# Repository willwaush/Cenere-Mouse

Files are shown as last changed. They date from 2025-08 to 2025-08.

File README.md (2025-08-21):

# 🖱️ Cenere Mouse (Open Source Tri-Mode Connectivity)

<p align="center">
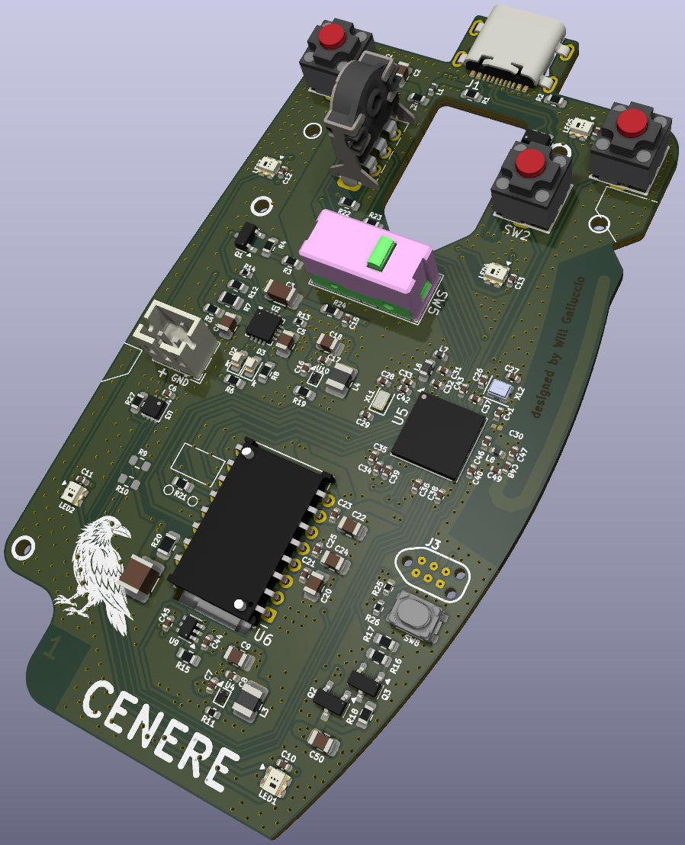
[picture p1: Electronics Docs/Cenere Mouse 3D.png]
3D Render of PCB
  
</p>

---

## 🔎 Project Overview

This project is an **open-source tri-mode connectivity gaming mouse**, designed around the **Nordic nRF52840** SoC.  
It supports three connectivity modes:

- **USB HID**  
- **Bluetooth Low Energy (BLE)**  
- **Nordic 2.4 GHz Wireless protocol**  

### ✨ Key Features
- Custom **monopole 2.4 GHz PCB antenna** optimized for the nRF52840  
- **PixArt PAW3395 optical sensor** for high-precision tracking  
- **Battery charging circuit** to support Bluetooth and Wireless power  
- **DC/DC Supply** to achieve maximum efficiency, low energy consumption
- **Addressable RGB LEDs** to optionally enable some aestethic glowing effect
- Fully open-source hardware and firmware*

---

## 📐 PCB Layer Previews

The design is a **4-layer PCB**, manufactured by **JLCPCB**, chosen for their reliable stackup and cost-effective prototyping services.  

<p align="center">
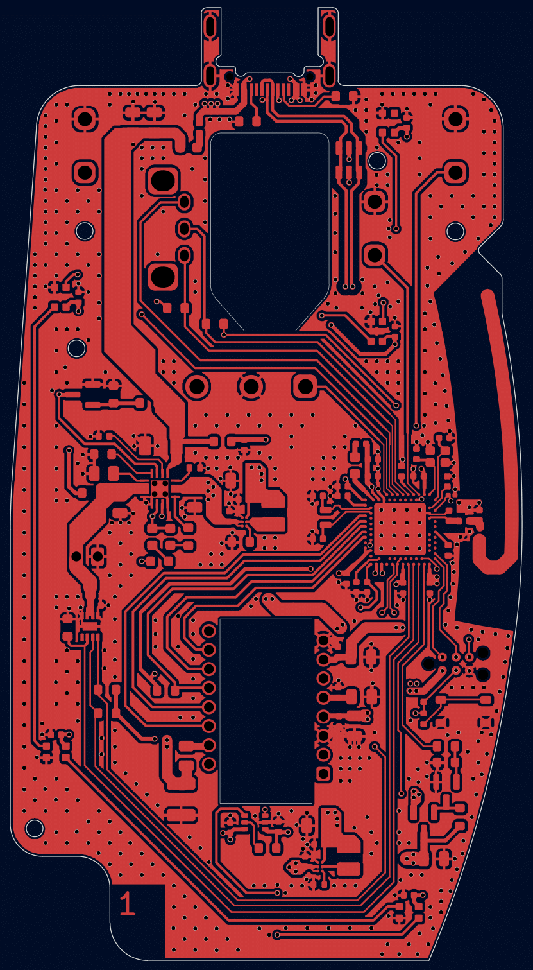
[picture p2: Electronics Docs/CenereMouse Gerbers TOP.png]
PCB Layer 1 - TOP
  
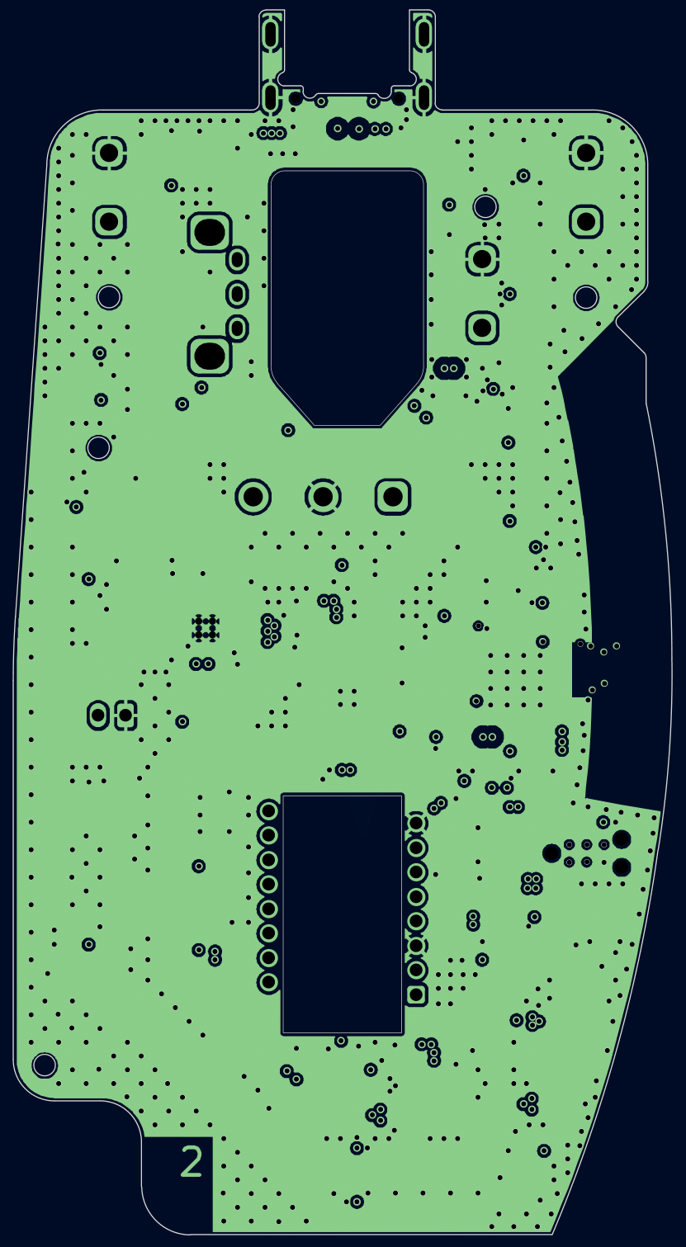
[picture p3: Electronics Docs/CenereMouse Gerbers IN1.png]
PCB Layer 2 - IN1
  
</p>

<p align="center">
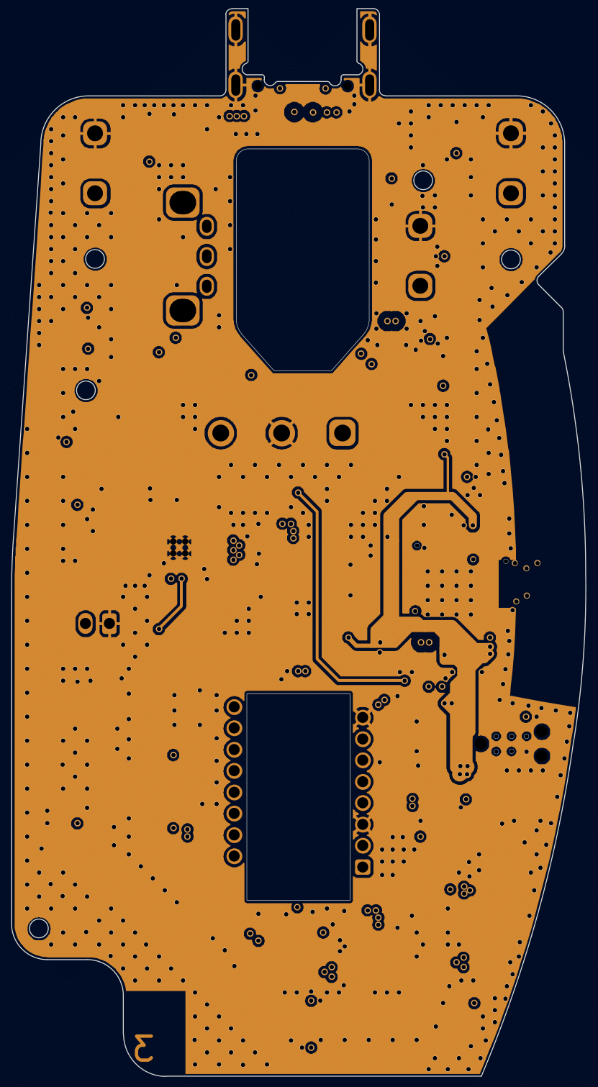
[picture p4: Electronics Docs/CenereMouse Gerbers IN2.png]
PCB Layer 3 - IN2
  
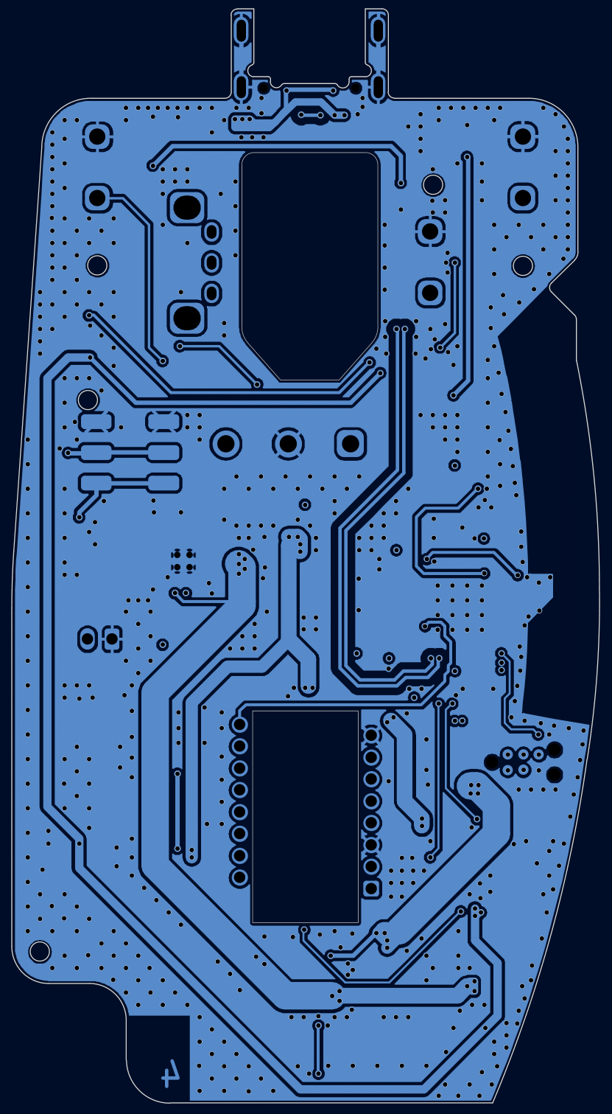
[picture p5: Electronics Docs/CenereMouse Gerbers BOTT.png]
PCB Layer 4 - BOTTOM
  
</p>

<p align="center">
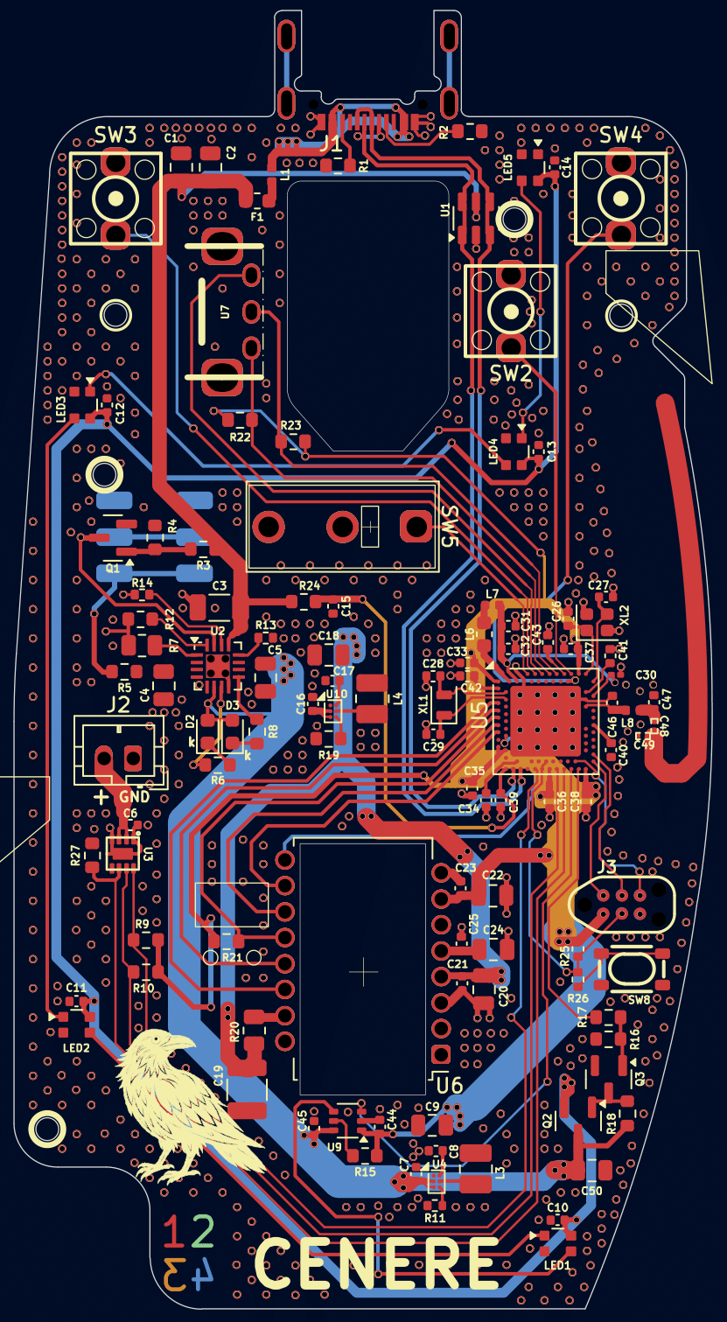
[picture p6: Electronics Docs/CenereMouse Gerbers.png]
All PCB Layers Together
  
</p>

---

## 🏗️ PCB Stackup (JLCPCB)

The board will be fabricated at **JLCPCB** with the following stackup:

- **Top Layer (Copper, 35 µm)** – signal + components  
- **Prepreg (0.2104 mm, Dk ≈ 4.4)** – dielectric (7628*1) 
- **Mid Layer 1 (Copper, 152 µm)** – ground/pwr
- **Core (1.065 mm, Dk ≈ 4.6)** – dielectric (FR4)
- **Mid Layer 2 (Copper, 152 µm)** – ground/pwr
- **Prepreg (0.2104 mm, Dk ≈ 4.4)** – dielectric (7628*1) 
- **Bottom Layer (Copper, 35 µm)** – signal + components

This configuration provides an easy to work with controlled impedance environment for the **high speed signals** as well as the **RF Section**.

---

## 🚀 Goals

- Provide a **fully open-source reference design** for hobbyists, makers, and researchers  
- Explore advanced **antenna design** on low-cost PCB fabrication  
- Enable experimentation with **custom gaming peripherals**  

---

## 📂 Repository Structure

/Kicad Files        → KiCad design files
/Electronics Docs   → Documentation, layer renders, diagrams

Work in progress..

---

## 📜 License

This project uses a **dual-license** model:

- **Software (Code)** → [GNU GPL v3.0](LICENSES/GPL-3.0.txt) with a **Non-Commercial Use Exception**  
  - You may use, modify, and redistribute the source code for **personal, educational, or research** purposes.  
  - **Commercial use is prohibited** without prior written permission.  
  - Attribution is required.

- **Hardware (Schematics, PCB Layouts, Documentation)** → [CC BY-NC 4.0](LICENSES/CC-BY-NC-4.0.txt)  
  - You may copy, redistribute, remix, and adapt the hardware files.  
  - **Commercial use is prohibited.**  
  - Attribution is required.

### Attribution Requirement

If you use this project (code or hardware) in your own work, you must credit:

**© [Your Name or Handle] – [Year]**  
Repo: [GitHub Repository URL]

Example attribution:  
> “Based on the open-source design/code by [Your Name], available at [GitHub Repo URL].”

### Commercial Use

For commercial licensing, please contact the author.

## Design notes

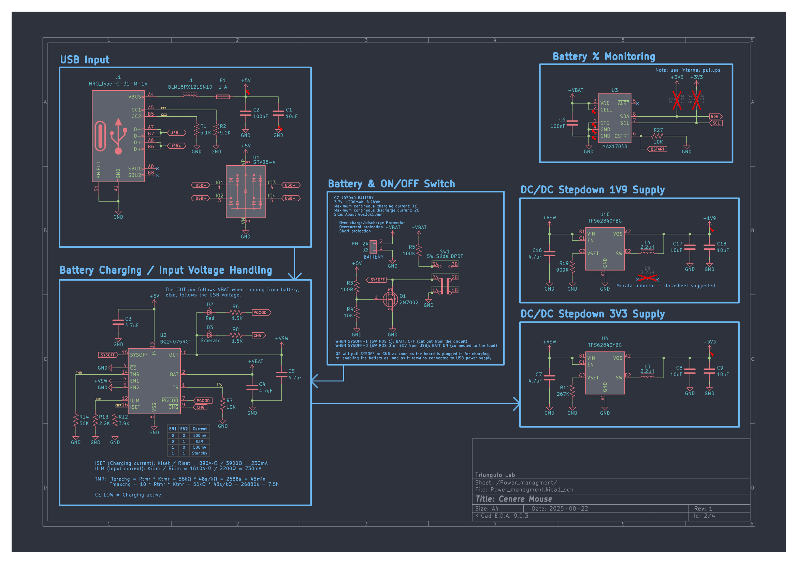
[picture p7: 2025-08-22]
Electronics Docs/Schematic-PowerManagment.png

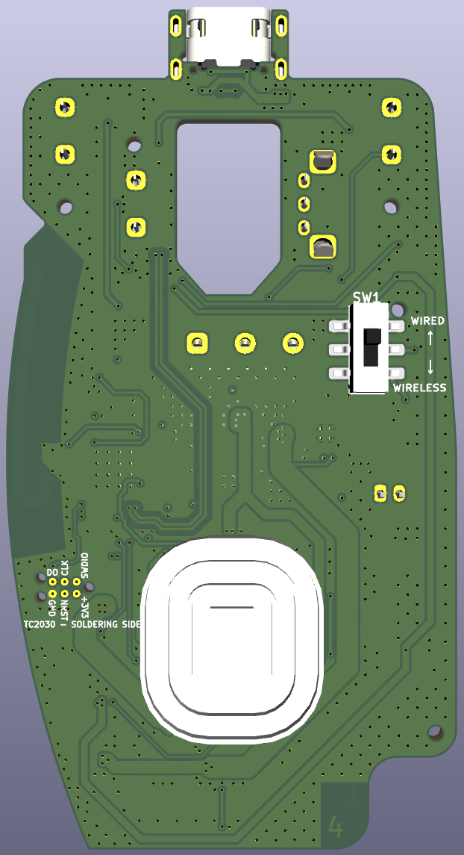
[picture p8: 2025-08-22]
Electronics Docs/Cenere Mouse Back 3D.png

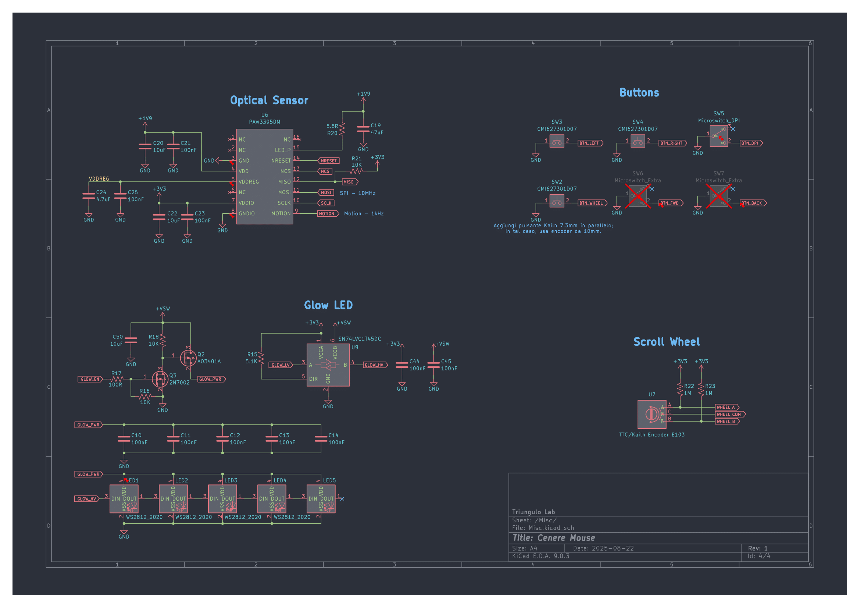
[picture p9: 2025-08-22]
Electronics Docs/Schematic-Misc.png

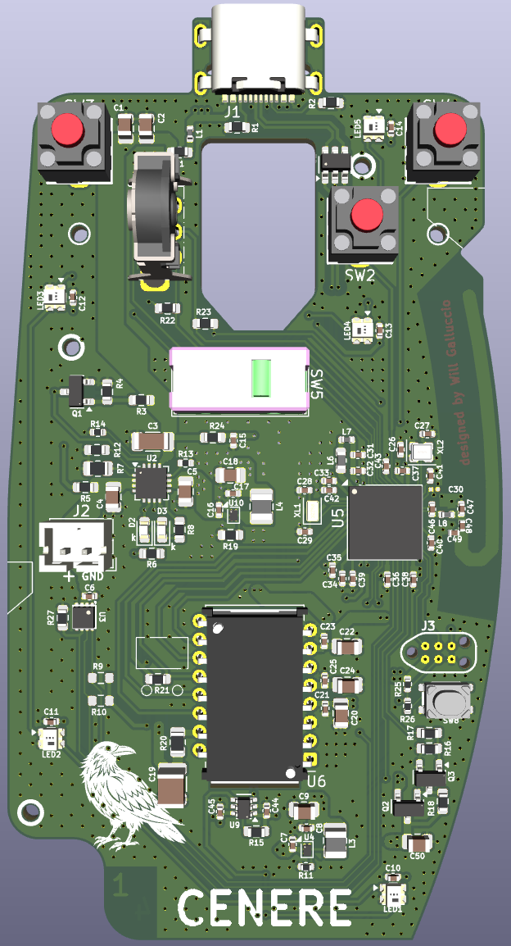
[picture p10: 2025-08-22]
Electronics Docs/Cenere Mouse Front 3D.png

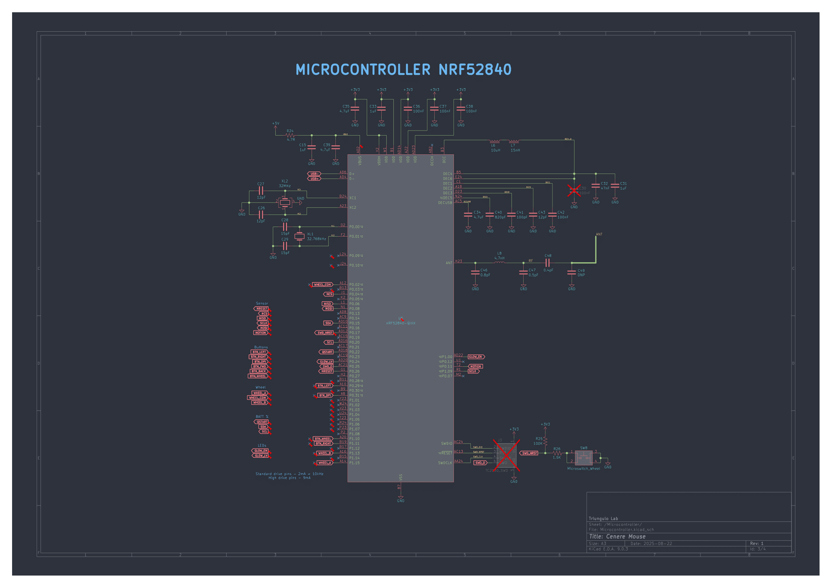
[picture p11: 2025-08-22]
Electronics Docs/Schematic-Microcontroller.png

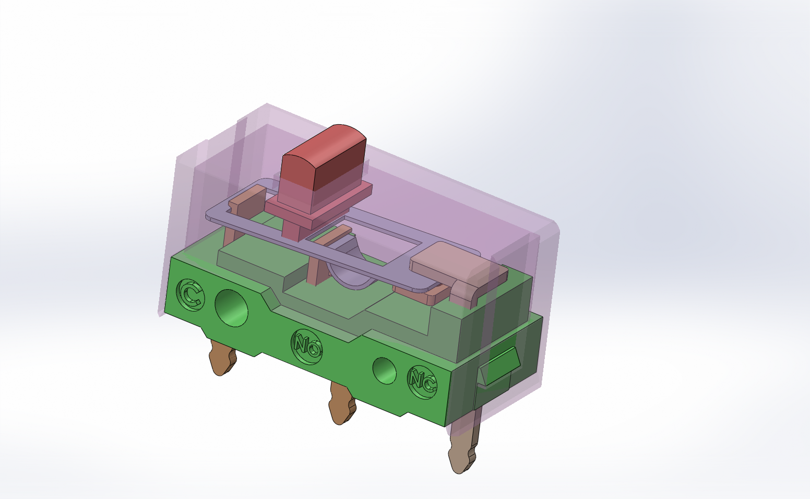
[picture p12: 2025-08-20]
Kicad Files/Extra Libs/tiny-switch-kailh-mouse-1.snapshot.2/SWITCH_MOUSE.PNG

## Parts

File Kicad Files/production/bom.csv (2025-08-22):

Designator | Footprint | Quantity | Value | LCSC Part #
C1, C18, C20, C22, C50, C9 | 0805 | 6 | 10uF | C95841
C10, C11, C12, C13, C14, C21, C23, C25, C36, C37, C38, C42, C44, C45, C6 | 0402 | 15 | 100nF | C307331
C15, C31, C33 | 0402 | 3 | 1uF | C52923
C16, C34, C35, C39, C7 | 0402 | 5 | 4.7uF | C23733
C17, C8 | 0402 | 2 | 10uF | C15525
C19 | 1210 | 1 | 47uF | C84494
C2 | 0805 | 1 | 100nF | C49678
C24, C4, C5 | 0805 | 3 | 4.7uF | C6119943
C26, C27, C43 | 0402 | 3 | 12pF | C1547
C28, C29 | 0402 | 2 | 15pF | C1548
C3 | 1206 | 1 | 4.7uF | C29823
C32 | 0402 | 1 | 47nF | C272875
C40 | 0402 | 1 | 820pF | C307452
C41 | 0402 | 1 | 100pF | C1546
C46 | 0402 | 1 | 0.8pF | C88902
C47 | 0402 | 1 | 0.5pF | C2912277
C48 | Z0201 RF Antenna Path | 1 | 0.4pF | C710805
D2 | 0603 | 1 | Red | C2286
D3 | 0603 | 1 | Emerald | C5121471
F1 | 0603 | 1 | 1 A | C151139
J1 | USB_C_Receptacle_HRO_TYPE-C-31-M-14 | 1 | HRO_Type-C-31-M-14 | C223907
J2 | JST_PH_B2B-PH-K_1x02_P2.00mm_Vertical | 1 | PH-2A | C2319
L1 | 0402 | 1 | BLM15PX121SN1D | C88970
L3, L4 | 1008 | 2 | 2.2uH | C5832372
L6 | 0603 | 1 | 10uH | C86752
L7 | 0402 | 1 | 15nH | C668460
L8 | 0402 | 1 | 4.7nH | C86065
LED1, LED2, LED3, LED4, LED5 | LED_WS2812_2020 | 5 | WS2812_2020 | C965555
Q1, Q3 | SOT-23 | 2 | 2N7002 | C8545
Q2 | SOT-23 | 1 | AO3401A | C347476
R1, R15, R2 | 0603 | 3 | 5.1K | C23186
R11 | 0402 | 1 | 267K | C2998050
R12 | 0603 | 1 | 3.9K | C23018
R13 | 0402 | 1 | 2.2K | C25879
R14 | 0402 | 1 | 56K | C25796
R16, R18, R21, R27, R4 | 0603 | 5 | 10K | C25804
R17, R3 | 0603 | 2 | 100R | C22775
R19 | 0603 | 1 | 909R | C471842
R20 | 0805 | 1 | 5.6R | C17729
R22, R23 | 0603 | 2 | 1M | C22935
R24 | 0603 | 1 | 4.7R | C23164
R25 | 0402 | 1 | 100K | C25741
R26 | 0402 | 1 | 1.5K | C25867
R5 | 0603 | 1 | 100K | C25803
R6, R8 | 0603 | 2 | 1.5K | C22843
R7 | 0805 | 1 | 10K | C17414
SW8 | KEY-SMD_4P-L4.2-W3.2-P2.20-LS4.6 | 1 | Microswitch_Wheel | C139797
U1 | SOT-23-6 | 1 | SRV05-4 | C2836319
U10, U4 | Texas_DSBGA-6_0.76x1.16mm_Layout2x3_P0.4mm | 2 | TPS62840YBG | C2071139
U2 | VQFN-16-1EP_3x3mm_P0.5mm_EP1.6x1.6mm_ThermalVias | 1 | BQ24075RGT | C15464
U3 | TDFN-8-EP_2x2mm_EP_0.8x1.38mm | 1 | MAX17048 | C2682616
U5 | Nordic_AQFN-73-1EP_7x7mm_P0.5mm | 1 | nRF52840-QIXX | C190794
U6 | PixArt_PDIP-16_10.9x16.2mm_P1.78mm | 1 | PAW3395DM
U9 | SOT-363_SC-70-6 | 1 | SN74LVC1T45DC | C9382
XL1 | Crystal_SMD_2012-2Pin_2.0x1.2mm | 1 | 32.768kHz | C7500573
XL2 | Crystal_SMD_2016-4Pin_2.0x1.6mm | 1 | 32MHz | C2965582

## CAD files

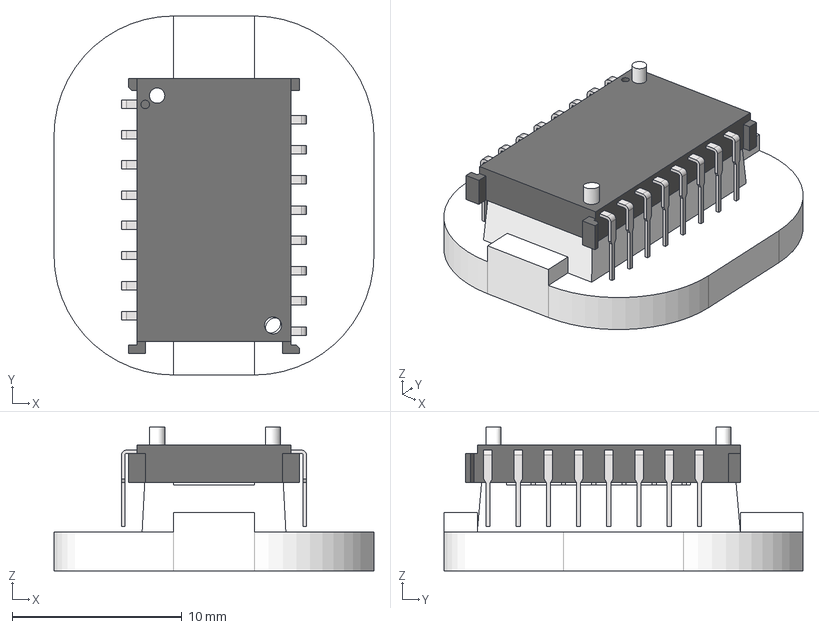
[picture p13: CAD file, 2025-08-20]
Kicad Files/Extra Libs/pmw3360dm-mouse-sensor-1.snapshot.1/PMW3360 v12.step
18.9 x 21.1 x 8.46 mm
Lead x 8
Lead(Mirror) x 8
Lens

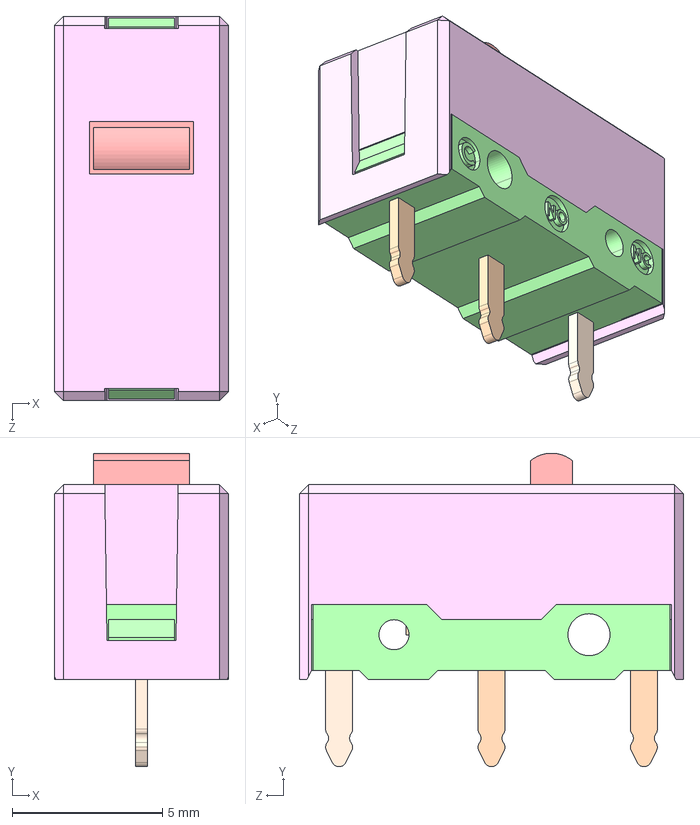
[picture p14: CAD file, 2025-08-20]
Kicad Files/Extra Libs/tiny-switch-kailh-mouse-1.snapshot.2/SWITCH_MOUSE.STEP
5.80 x 10.4 x 12.8 mm

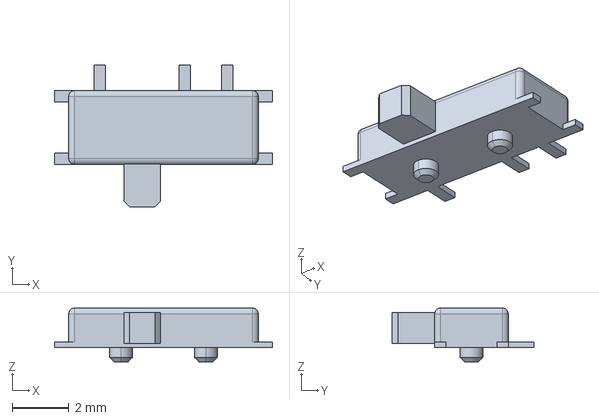
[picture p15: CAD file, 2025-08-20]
Kicad Files/Extra Libs/switch_kps-1290.stp
7.70 x 5.00 x 1.90 mm

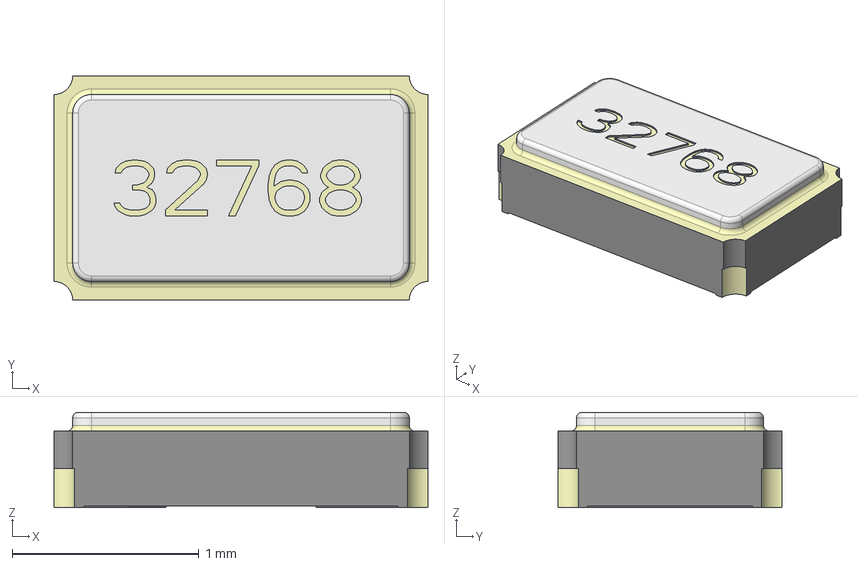
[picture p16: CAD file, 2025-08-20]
Kicad Files/Extra Libs/xsc2012.stp
2.00 x 1.20 x 0.51 mm

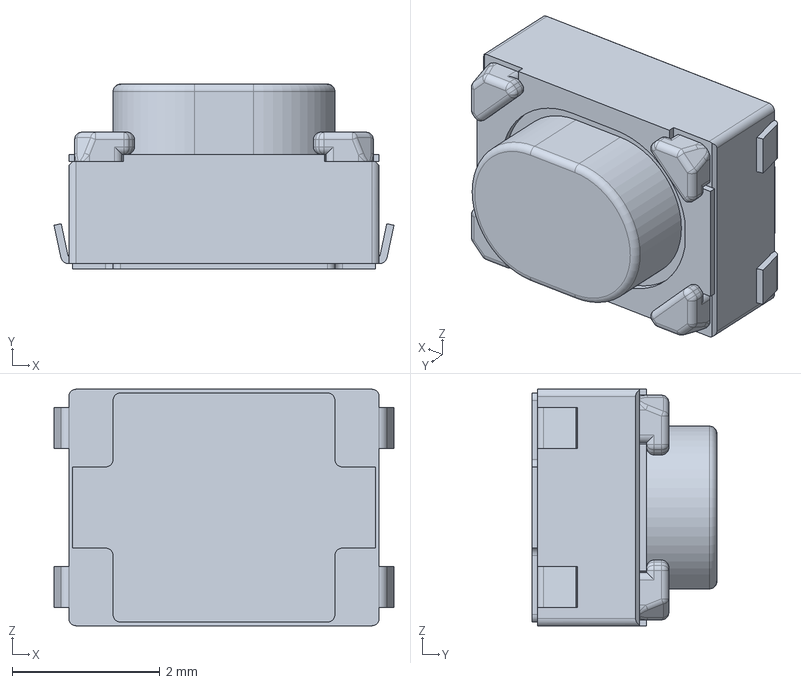
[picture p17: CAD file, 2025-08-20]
Kicad Files/Extra Libs/skrpace010.stp
4.60 x 2.50 x 3.20 mm

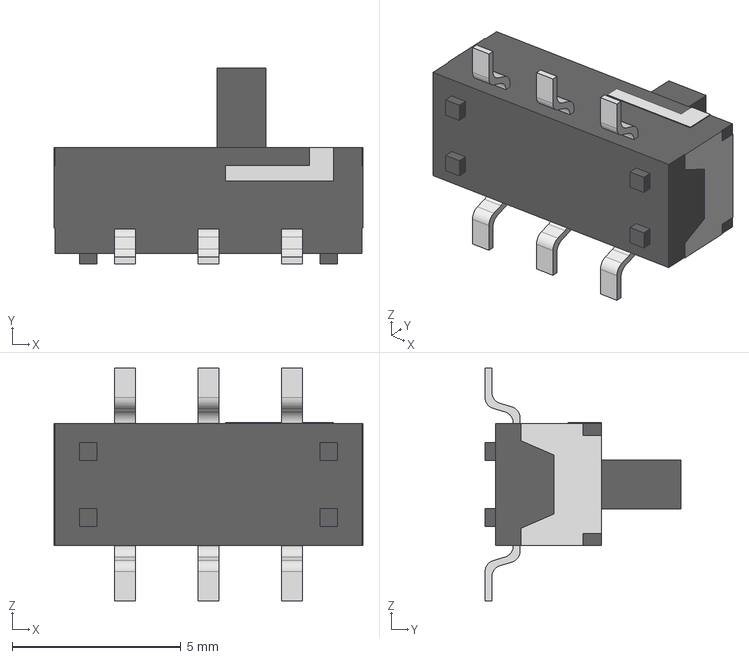
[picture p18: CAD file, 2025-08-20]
Kicad Files/Extra Libs/Selector Switch - MSS22D18.stp
9.17 x 5.82 x 6.91 mm

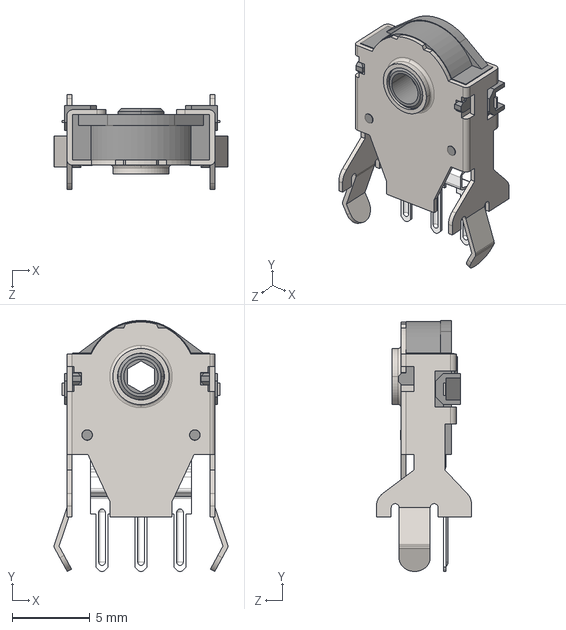
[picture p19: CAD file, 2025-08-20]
Kicad Files/Extra Libs/Alps Encoder 10mm EC10E1220501.stp
11.1 x 16.1 x 6.10 mm

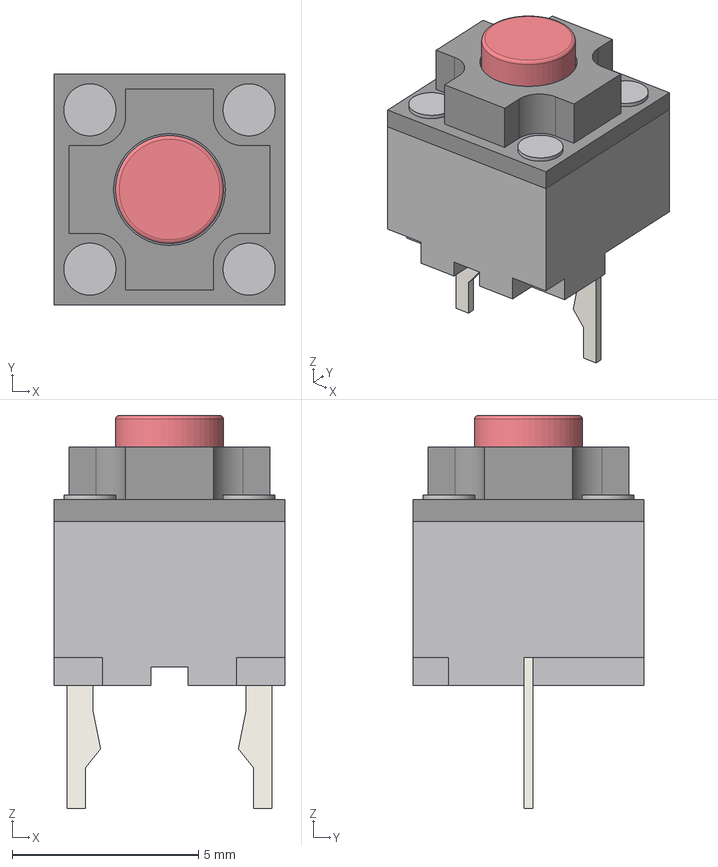
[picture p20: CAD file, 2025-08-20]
Kicad Files/Extra Libs/microSwitch_Kailh_6x6x7.3 (MI627301D07).step
6.20 x 6.20 x 10.6 mm

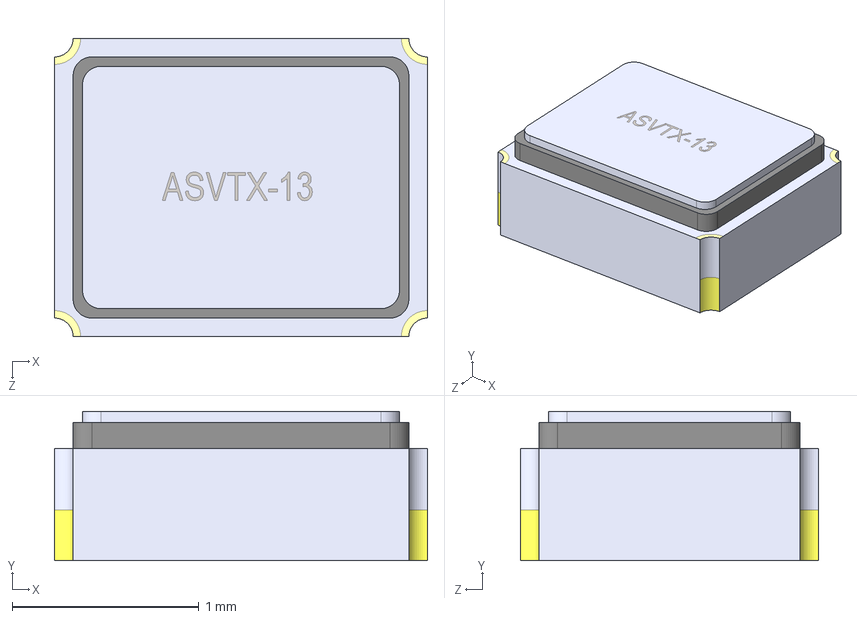
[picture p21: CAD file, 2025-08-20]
Kicad Files/Extra Libs/ASVTX-13.STEP
2.00 x 0.8 x 1.60 mm

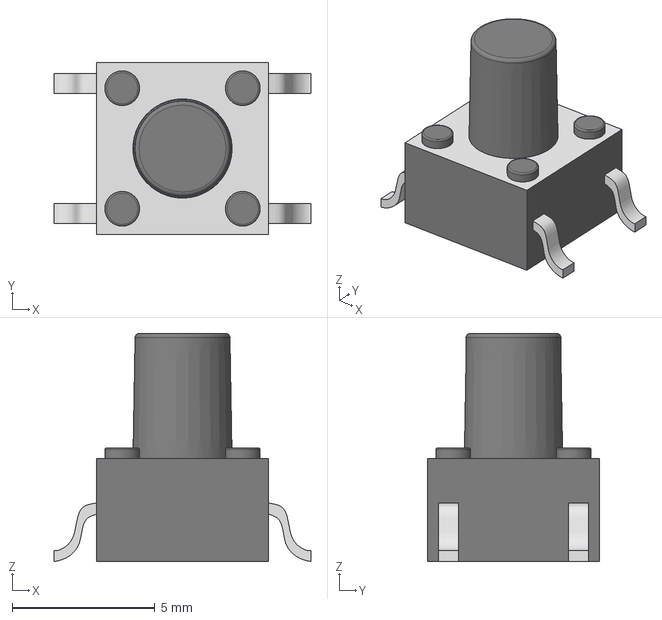
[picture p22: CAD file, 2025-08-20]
Kicad Files/Extra Libs/Tactal Switch - SMD 6x6x8.stp
9.02 x 6.03 x 8.00 mm

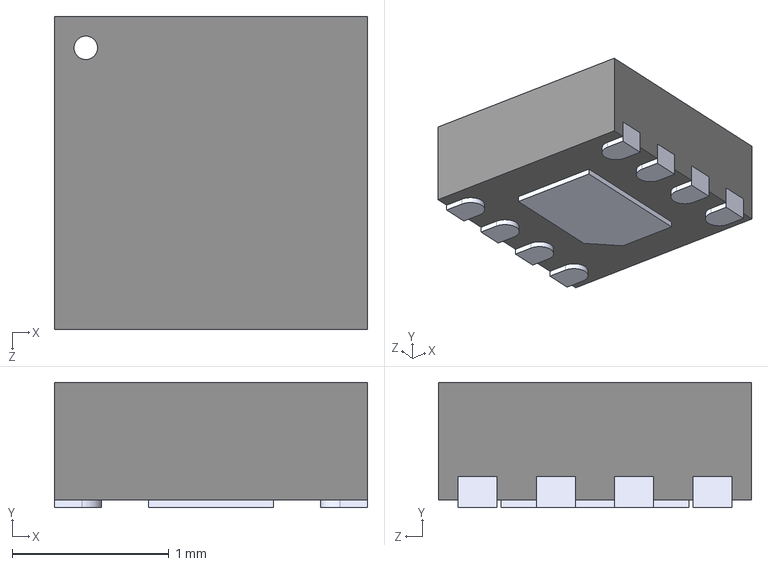
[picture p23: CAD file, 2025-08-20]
Kicad Files/Extra Libs/MAX17048G-T10--3DModel-STEP-510211.STEP
2.00 x 0.8 x 2.00 mm

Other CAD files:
Kicad Files/Extra Libs/pmw3360dm-mouse-sensor-1.snapshot.1/PMW3360 v12.f3d

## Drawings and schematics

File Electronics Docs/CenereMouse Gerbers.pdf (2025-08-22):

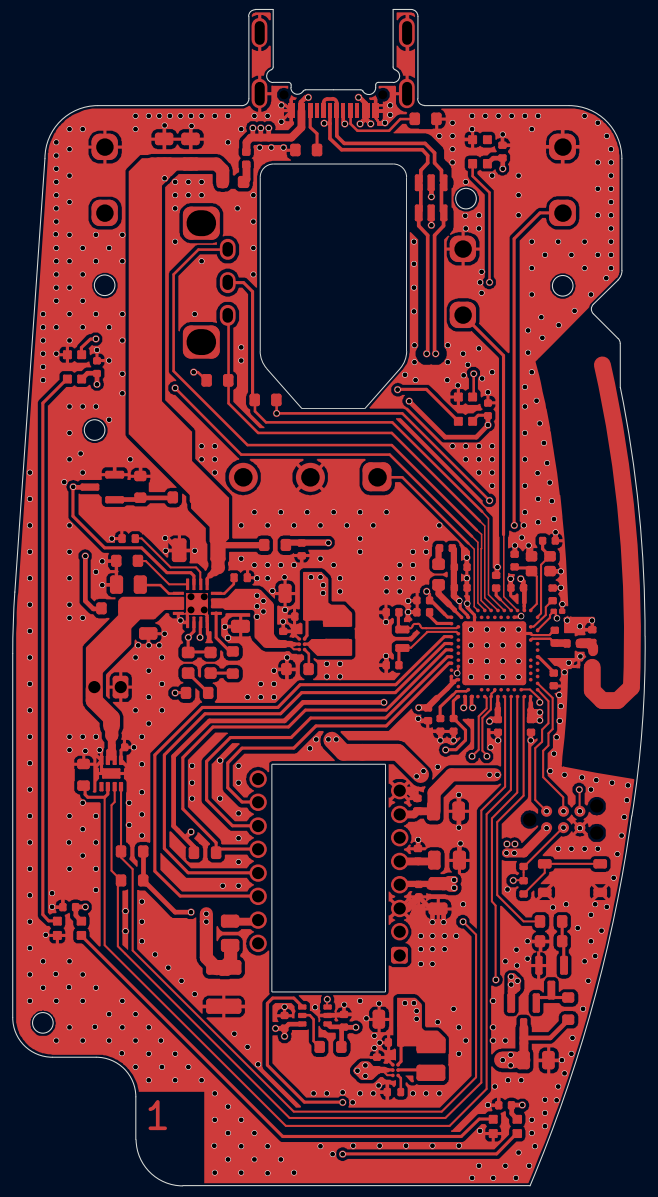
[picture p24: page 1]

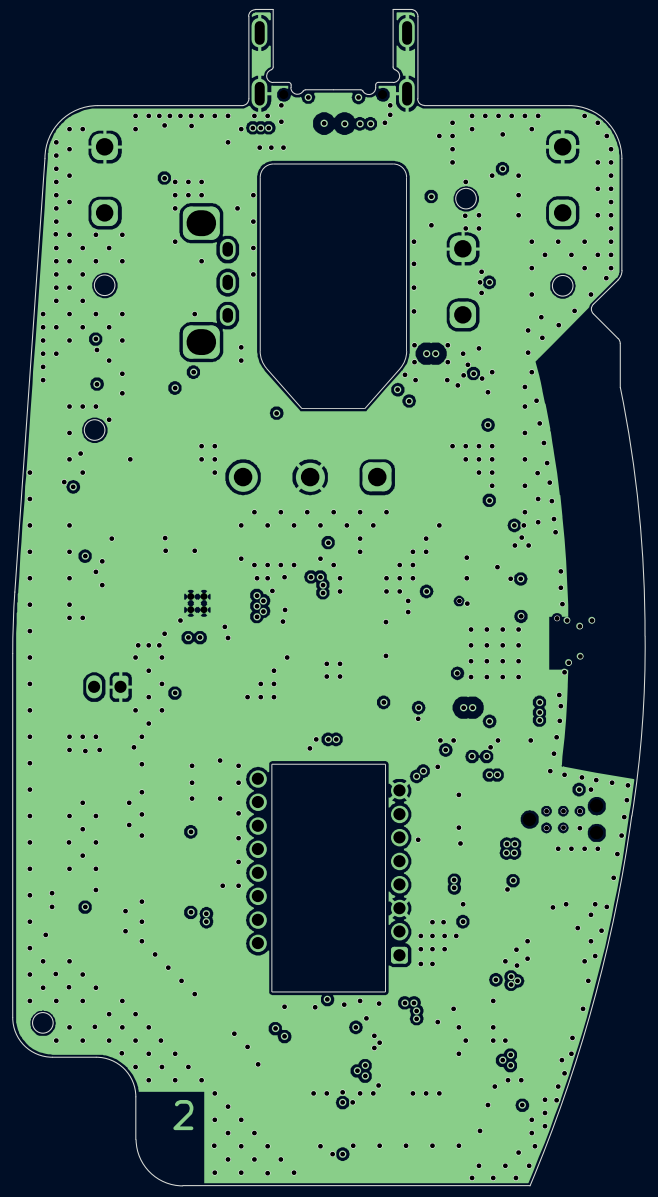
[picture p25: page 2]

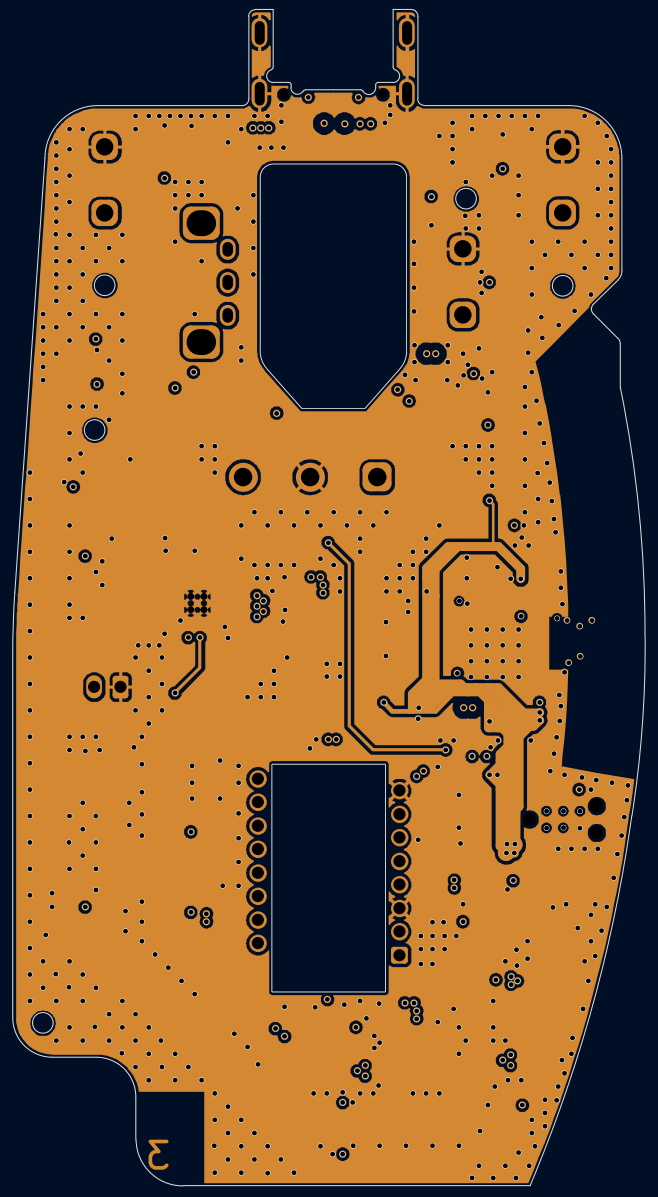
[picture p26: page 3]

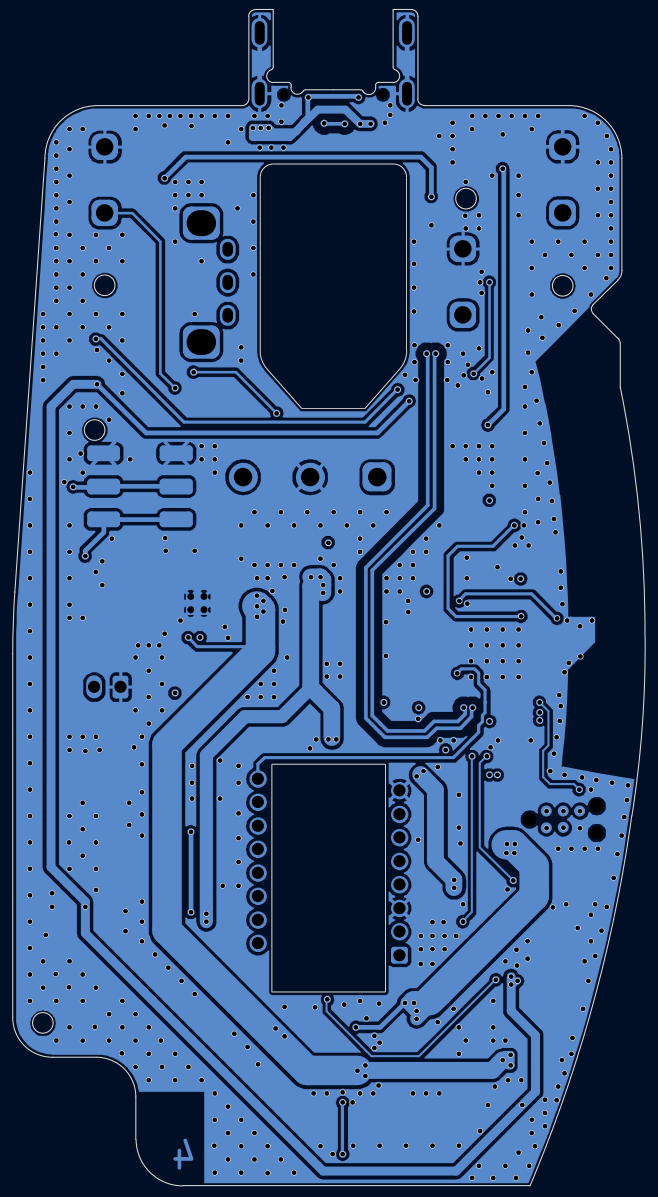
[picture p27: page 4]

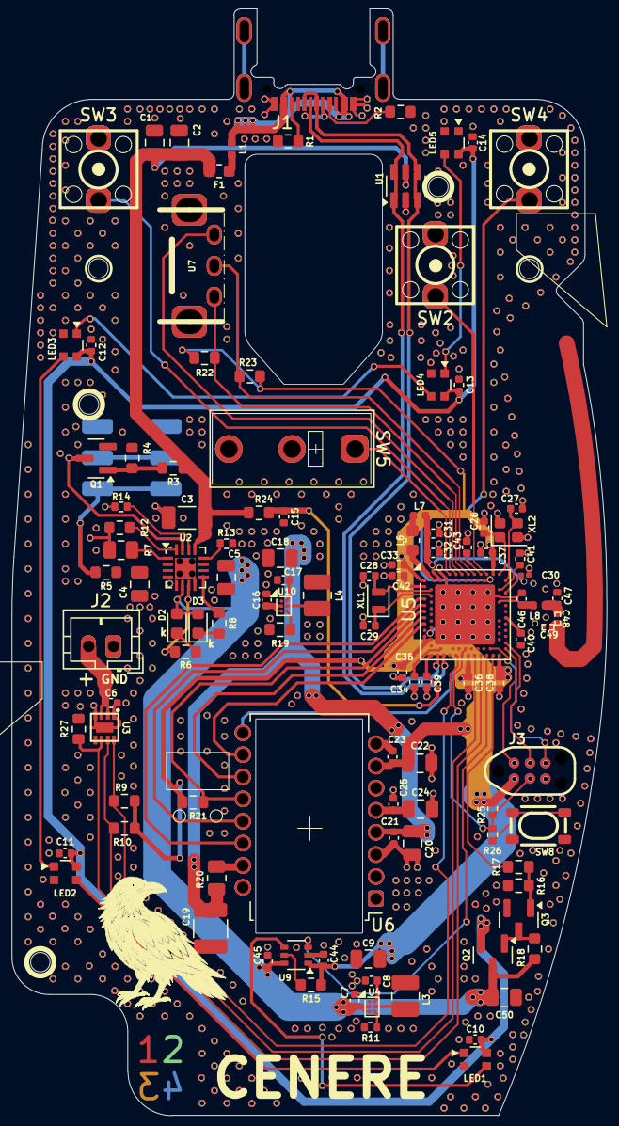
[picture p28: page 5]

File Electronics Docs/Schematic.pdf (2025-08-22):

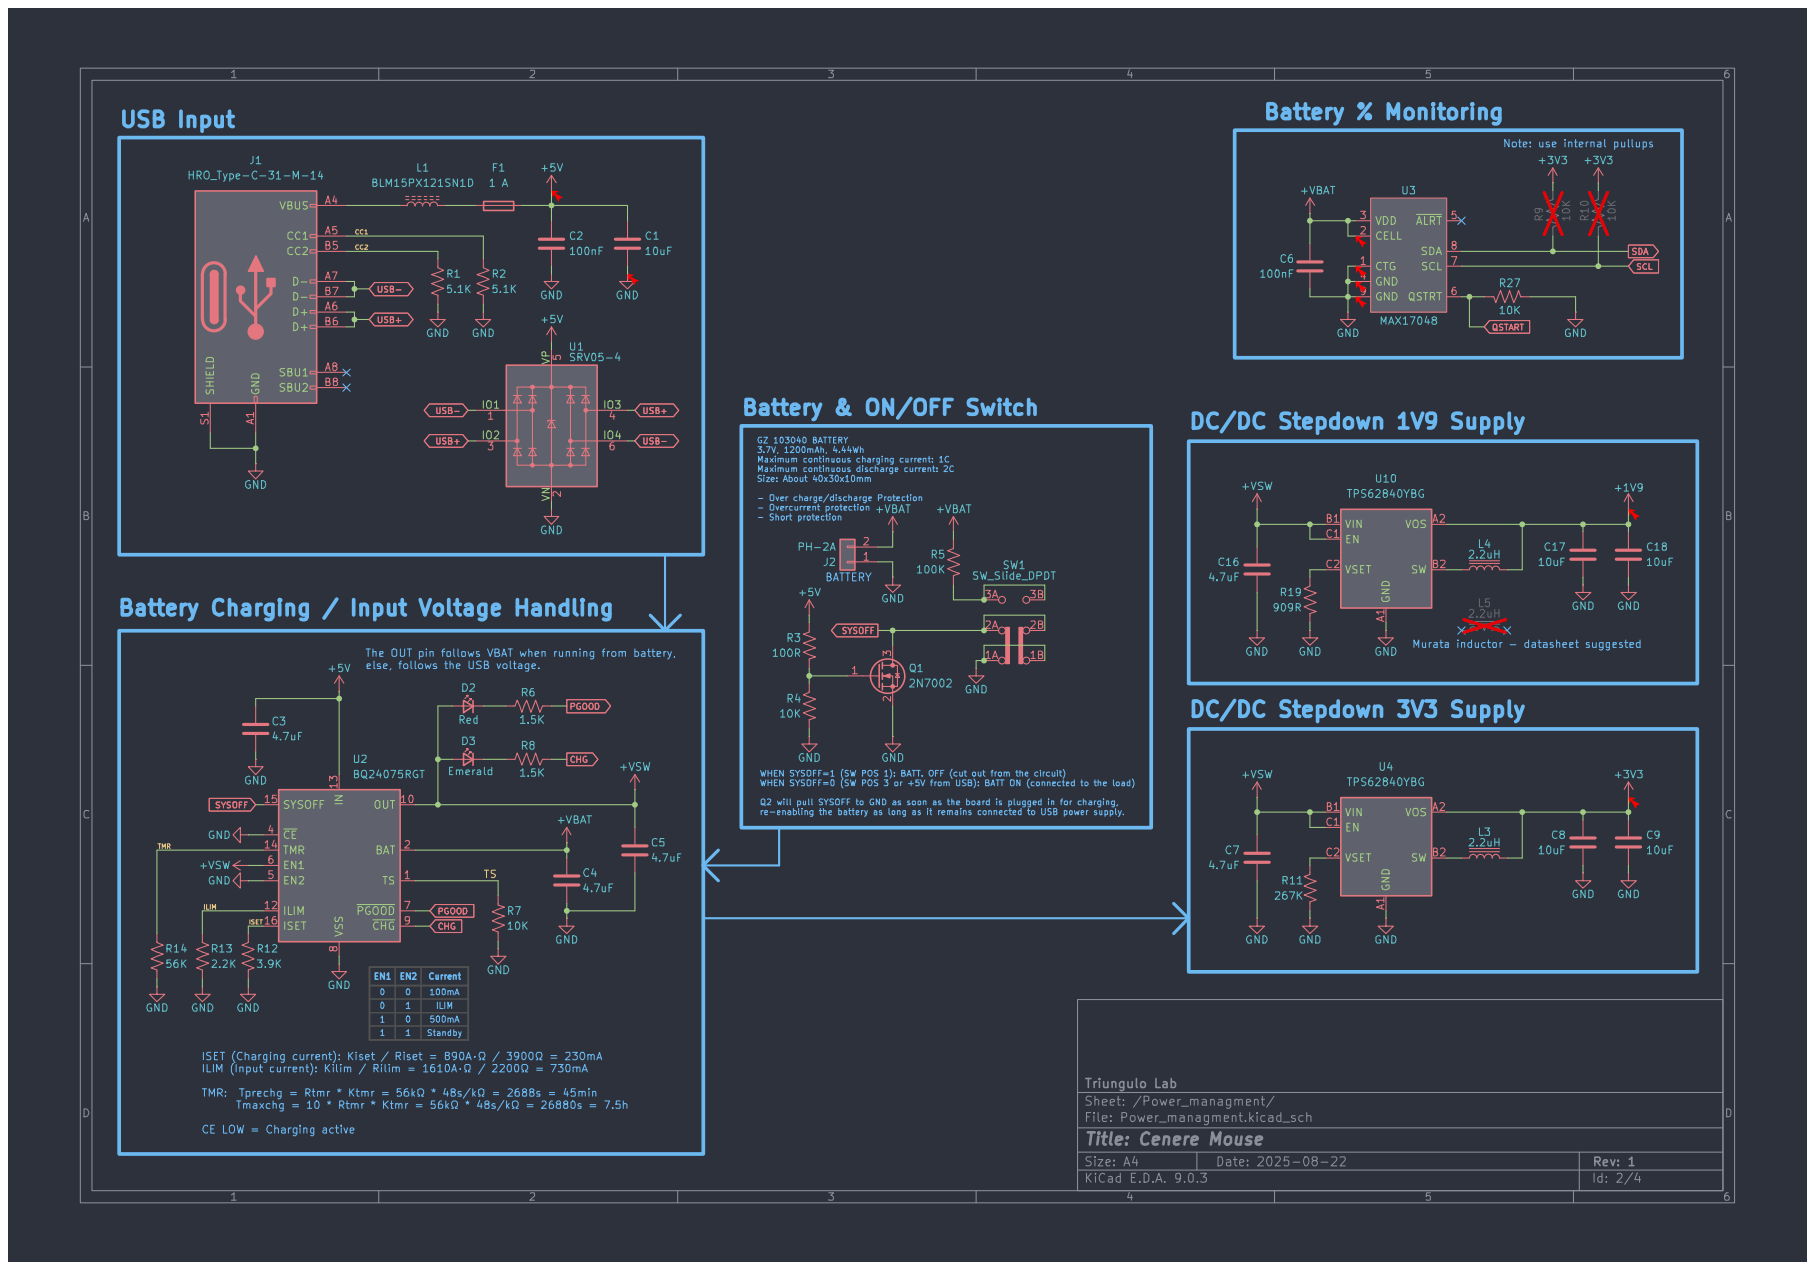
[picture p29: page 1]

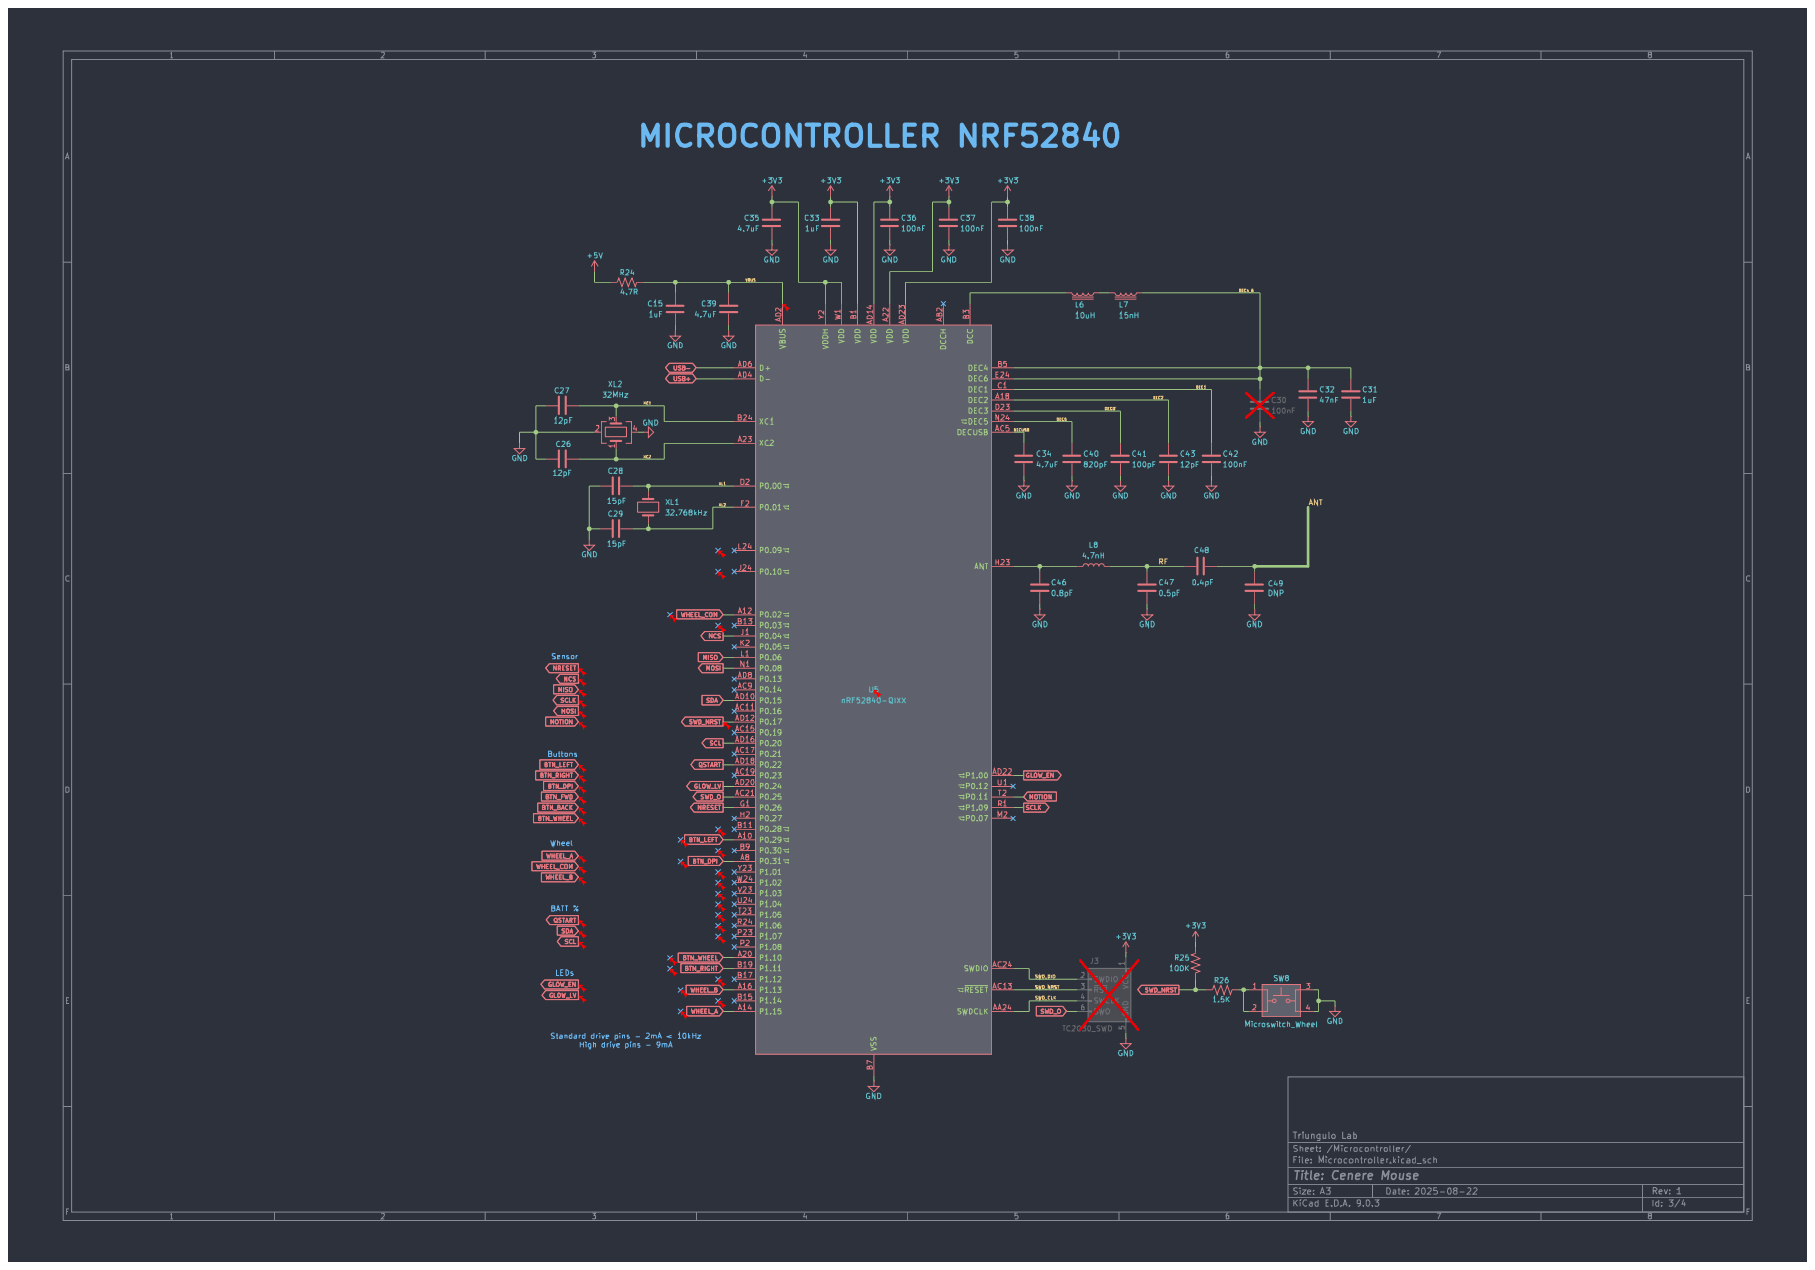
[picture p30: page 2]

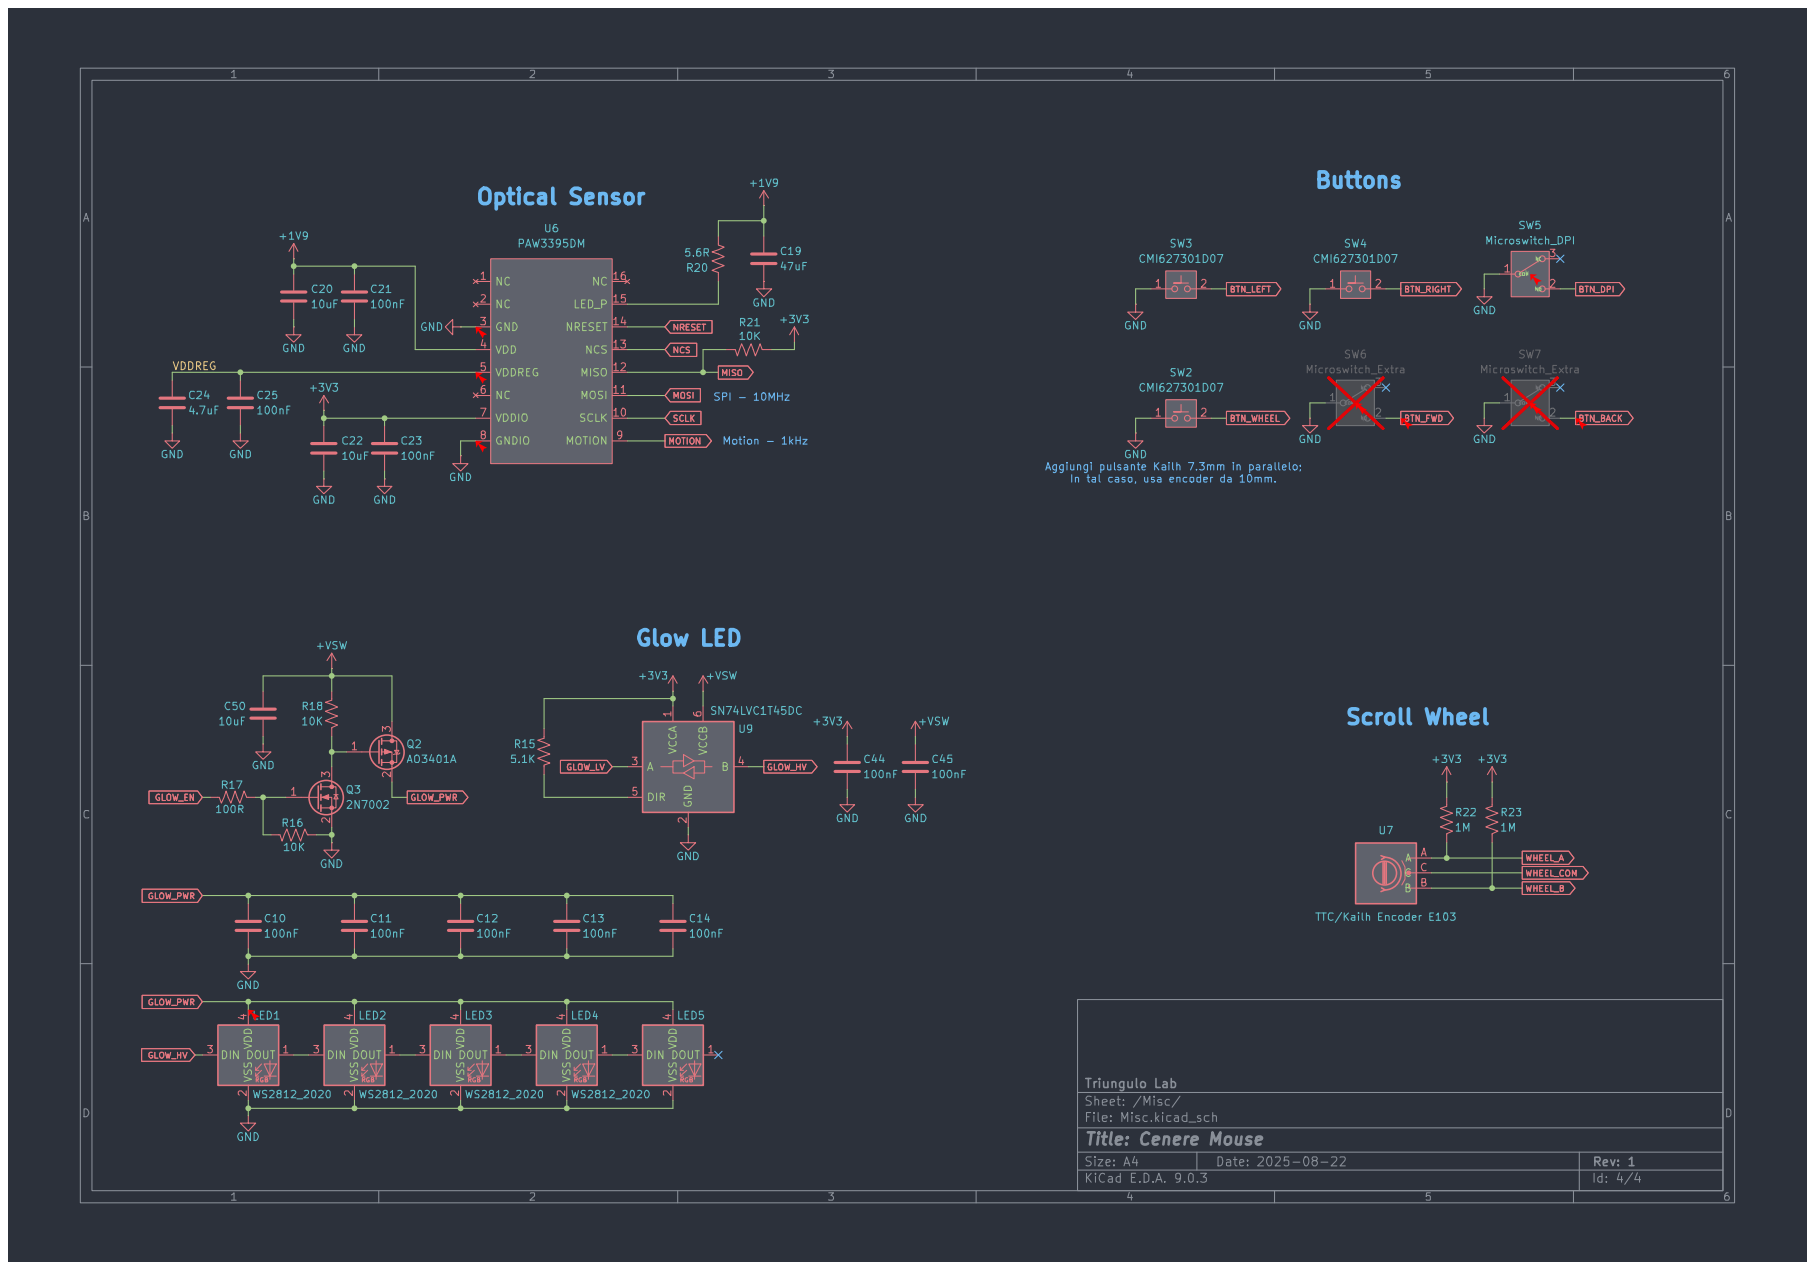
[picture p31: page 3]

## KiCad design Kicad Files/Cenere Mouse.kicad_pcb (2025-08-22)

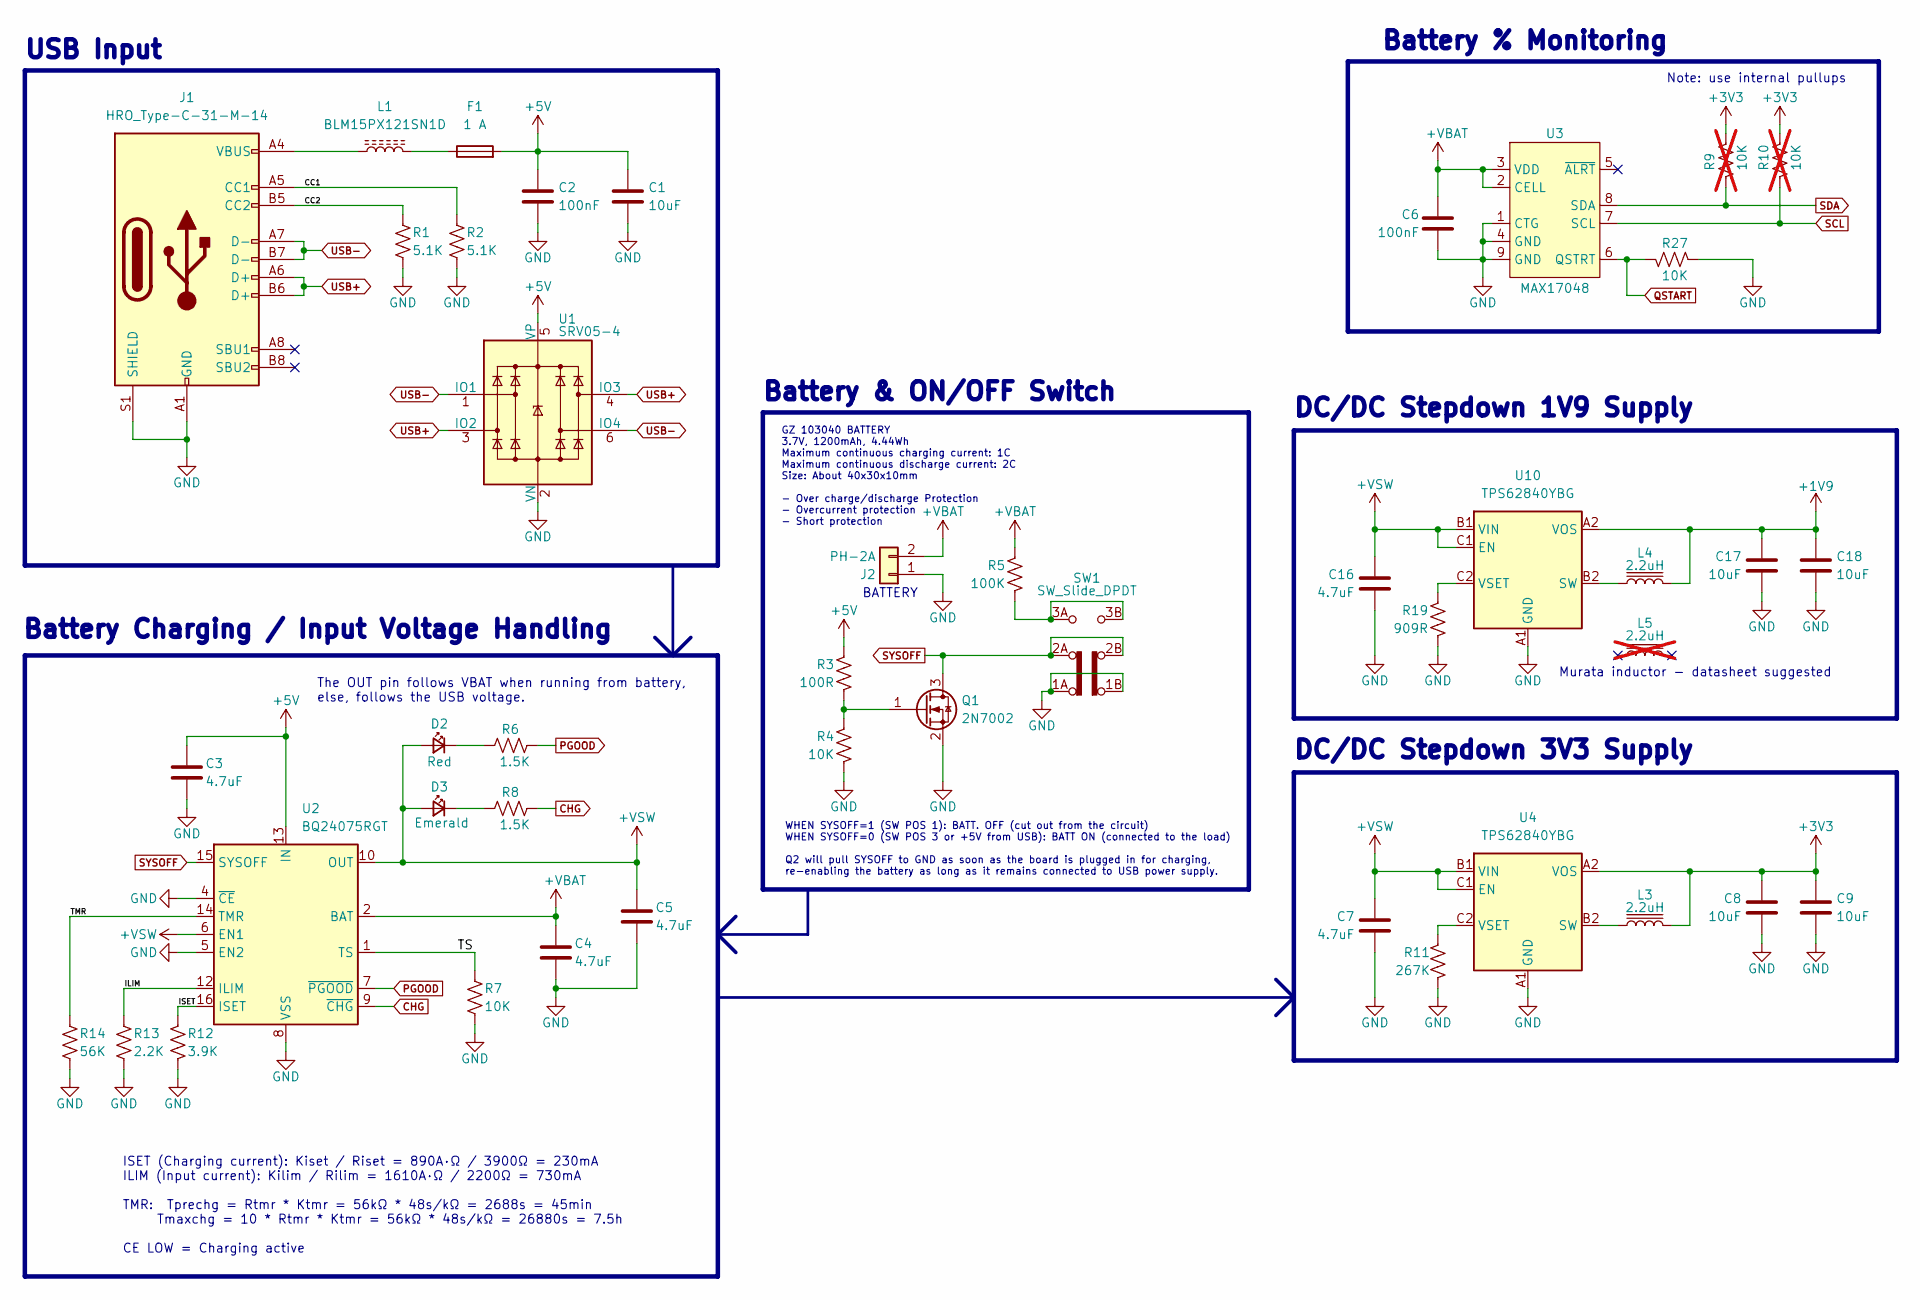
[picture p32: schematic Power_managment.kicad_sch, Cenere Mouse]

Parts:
C1, C9, C18: 10uF; C_0805_2012Metric; Part Number CL21B106KOQNNNE; JLCPCB PN C95841
C2: 100nF; C_0805_2012Metric; Part Number CC0805KRX7R9BB104; JLCPCB PN C49678
C3: 4.7uF; C_1206_3216Metric; Part Number 1206B475K500NT; JLCPCB PN C29823
C4, C5: 4.7uF; C_0805_2012Metric; Part Number CGA0805X7R475K350MT; JLCPCB PN C6119943
C6: 100nF; C_0402_1005Metric; Part Number CL05B104KB54PNC; JLCPCB PN C307331
C7, C16: 4.7uF; C_0402_1005Metric; Part Number CL05A475MP5NRNC; JLCPCB PN C23733
C8, C17: 10uF; C_0402_1005Metric; Part Number CL05A106MQ5NUNC; JLCPCB PN C15525
D2: Red; LED_0603_1608Metric; Part Number KT-0603R; JLCPCB PN C2286
D3: Emerald; LED_0603_1608Metric; Part Number APTD1608CGCK; JLCPCB PN C5121471
F1: 1 A; Fuse_0603_1608Metric; Part Number 0467001.NRHF; JLCPCB PN C151139
J1: HRO_Type-C-31-M-14; USB_C_Receptacle_HRO_TYPE-C-31-M-14; Part Number TYPE-C-31-M-14; JLCPCB PN C223907
J2: PH-2A; JST_PH_B2B-PH-K_1x02_P2.00mm_Vertical; Part Number PH-2A; JLCPCB PN C2319
L1: BLM15PX121SN1D; L_0402_1005Metric; Part Number BLM15PX121SN1D; JLCPCB PN C88970
L3, L4: 2.2uH; L_1008_2520Metric; Part Number FTC252012S2R2MBCA; JLCPCB PN C5832372
L5: 2.2uH; L_Murata_DFE201610P; Part Number DFE201612E-2R2M=P2; JLCPCB PN C337893; not fitted
Q1: 2N7002; SOT-23; Part Number 2N7002; JLCPCB PN C8545
R1, R2: 5.1K; R_0603_1608Metric; Part Number 0603WAF5101T5E; JLCPCB PN C23186
R3: 100R; R_0603_1608Metric; Part Number 0603WAF1000T5E; JLCPCB PN C22775
R4, R27: 10K; R_0603_1608Metric; Part Number 0603WAF1002T5E; JLCPCB PN C25804
R5: 100K; R_0603_1608Metric; Part Number 0603WAF1003T5E; JLCPCB PN C25803
R6, R8: 1.5K; R_0603_1608Metric; Part Number 0603WAF1501T5E; JLCPCB PN C22843
R7: 10K; R_0805_2012Metric; Part Number 0805W8F1002T5E; JLCPCB PN C17414
R9, R10: 10K; R_0603_1608Metric; Part Number 0603WAF1002T5E; JLCPCB PN C25804; not fitted
R11: 267K; R_0402_1005Metric; Part Number FRC0402F2673TS; JLCPCB PN C2998050
R12: 3.9K; R_0603_1608Metric; Part Number 0603WAF3901T5E; JLCPCB PN C23018
R13: 2.2K; R_0402_1005Metric; Part Number 0402WGF2201TCE; JLCPCB PN C25879
R14: 56K; R_0402_1005Metric; Part Number 0402WGF5602TCE; JLCPCB PN C25796
R19: 909R; R_0603_1608Metric; Part Number RC0603DR-07909RL; JLCPCB PN C471842
SW1: SW_Slide_DPDT; SLIDE SMD DPDT
U1: SRV05-4; SOT-23-6; Part Number SRV05-4; JLCPCB PN C2836319
U2: BQ24075RGT; VQFN-16-1EP_3x3mm_P0.5mm_EP1.6x1.6mm_ThermalVias; Part Number BQ24075RGTR; JLCPCB PN C15464
U3: MAX17048; TDFN-8-EP_2x2mm_EP_0.8x1.38mm; Part Number MAX17048G+T10; JLCPCB PN C2682616
U4, U10: TPS62840YBG; Texas_DSBGA-6_0.76x1.16mm_Layout2x3_P0.4mm; Part Number TPS62840YBGR; JLCPCB PN C2071139

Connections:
+1V9: C17.1, C18.1, L4.2, U10.A2 (VOS); also elsewhere on the board
+3V3: C8.1, C9.1, L3.2, R9.2, R10.2, U4.A2 (VOS); also elsewhere on the board
+5V: C1.1, C2.1, C3.1, F1.2, R3.1, U1.5 (VP), U2.13 (IN); also elsewhere on the board
+VBAT: C4.1, C6.1, J2.2, R5.1, U2.2 (BAT), U2.3 (BAT), U3.2 (CELL), U3.3 (VDD)
+VSW: C5.1, C7.1, C16.1, D2.2 (A), D3.2 (A), U2.6 (EN1), U2.10 (OUT), U2.11 (OUT), U4.B1 (VIN), U4.C1 (EN), U10.B1 (VIN), U10.C1 (EN); also elsewhere on the board
/Power_managment/CC1: J1.A5 (CC1), R2.1
/Power_managment/CC2: J1.B5 (CC2), R1.1
/Power_managment/ILIM: R13.1, U2.12 (ILIM)
/Power_managment/ISET: R12.1, U2.16 (ISET)
/Power_managment/TMR: R14.1, U2.14 (TMR)
/Power_managment/TS: R7.1, U2.1 (TS)
CHG: R8.2, U2.9 (~CHG)
GND: C1.2, C2.2, C3.2, C4.2, C5.2, C6.2, C7.2, C8.2, C9.2, C16.2, C17.2, C18.2, J1.A1 (GND), J1.A12 (GND), J1.B1 (GND), J1.B12 (GND), J1.S1 (SHIELD), J2.1, Q1.2 (S), R1.2, R2.2, R4.2, R7.2, R11.2, R12.2, R13.2, R14.2, R19.2, R27.2, SW1.1A (NC), SW1.1B (NC), U1.2 (VN), U2.4 (~CE), U2.5 (EN2), U2.8 (VSS), U2.17 (VSS), U3.1 (CTG), U3.4 (GND), U3.9 (GND), U4.A1 (GND), U10.A1 (GND); also elsewhere on the board
unnamed: D2.1 (K), R6.1
unnamed: D3.1 (K), R8.1
unnamed: F1.1, L1.2
unnamed: J1.A4 (VBUS), J1.A9 (VBUS), J1.B4 (VBUS), J1.B9 (VBUS), L1.1
unnamed: Q1.1 (G), R3.2, R4.1
unnamed: R5.2, SW1.3A (NO), SW1.3B (NO)
unnamed: L3.1, U4.B2 (SW)
unnamed: R11.1, U4.C2 (VSET)
unnamed: L4.1, U10.B2 (SW)
unnamed: R19.1, U10.C2 (VSET)
PGOOD: R6.2, U2.7 (~PGOOD)
QSTART: R27.1, U3.6 (QSTRT); also elsewhere on the board
SCL: R10.1, U3.7 (SCL); also elsewhere on the board
SDA: R9.1, U3.8 (SDA); also elsewhere on the board
SYSOFF: Q1.3 (D), SW1.2A (COM), SW1.2B (COM), U2.15 (SYSOFF)
USB+: J1.A6 (D+), J1.B6 (D+), U1.3 (IO2), U1.4 (IO3); also elsewhere on the board
USB-: J1.A7 (D-), J1.B7 (D-), U1.1 (IO1), U1.6 (IO4); also elsewhere on the board

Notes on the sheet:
Note: use internal pullups
The OUT pin follows VBAT when running from battery, else, follows the USB voltage.
BATTERY
USB Input
GZ 103040 BATTERY 3.7V, 1200mAh, 4.44Wh Maximum continuous charging current: 1C Maximum continuous discharge current: 2C Size: About 40x30x10mm - Over charge/discharge Protection - Overcurrent protection - Short protection
DC/DC Stepdown 1V9 Supply
WHEN SYSOFF=1 (SW POS 1): BATT. OFF (cut out from the circuit) WHEN SYSOFF=0 (SW POS 3 or +5V from USB): BATT ON (connected to the load) Q2 will pull SYSOFF to GND as soon as the board is plugged in for charging, re-enabling the battery as long as it remains connected to USB power supply.
Battery % Monitoring
Murata inductor - datasheet suggested
Battery Charging / Input Voltage Handling
DC/DC Stepdown 3V3 Supply
Battery & ON/OFF Switch
ISET (Charging current): Kiset / Riset = 890A·Ω / 3900Ω = 230mA ILIM (Input current): Kilim / Rilim = 1610A·Ω / 2200Ω = 730mA TMR: Tprechg = Rtmr * Ktmr = 56kΩ * 48s/kΩ = 2688s = 45min Tmaxchg = 10 * Rtmr * Ktmr = 56kΩ * 48s/kΩ = 26880s = 7.5h CE LOW = Charging active

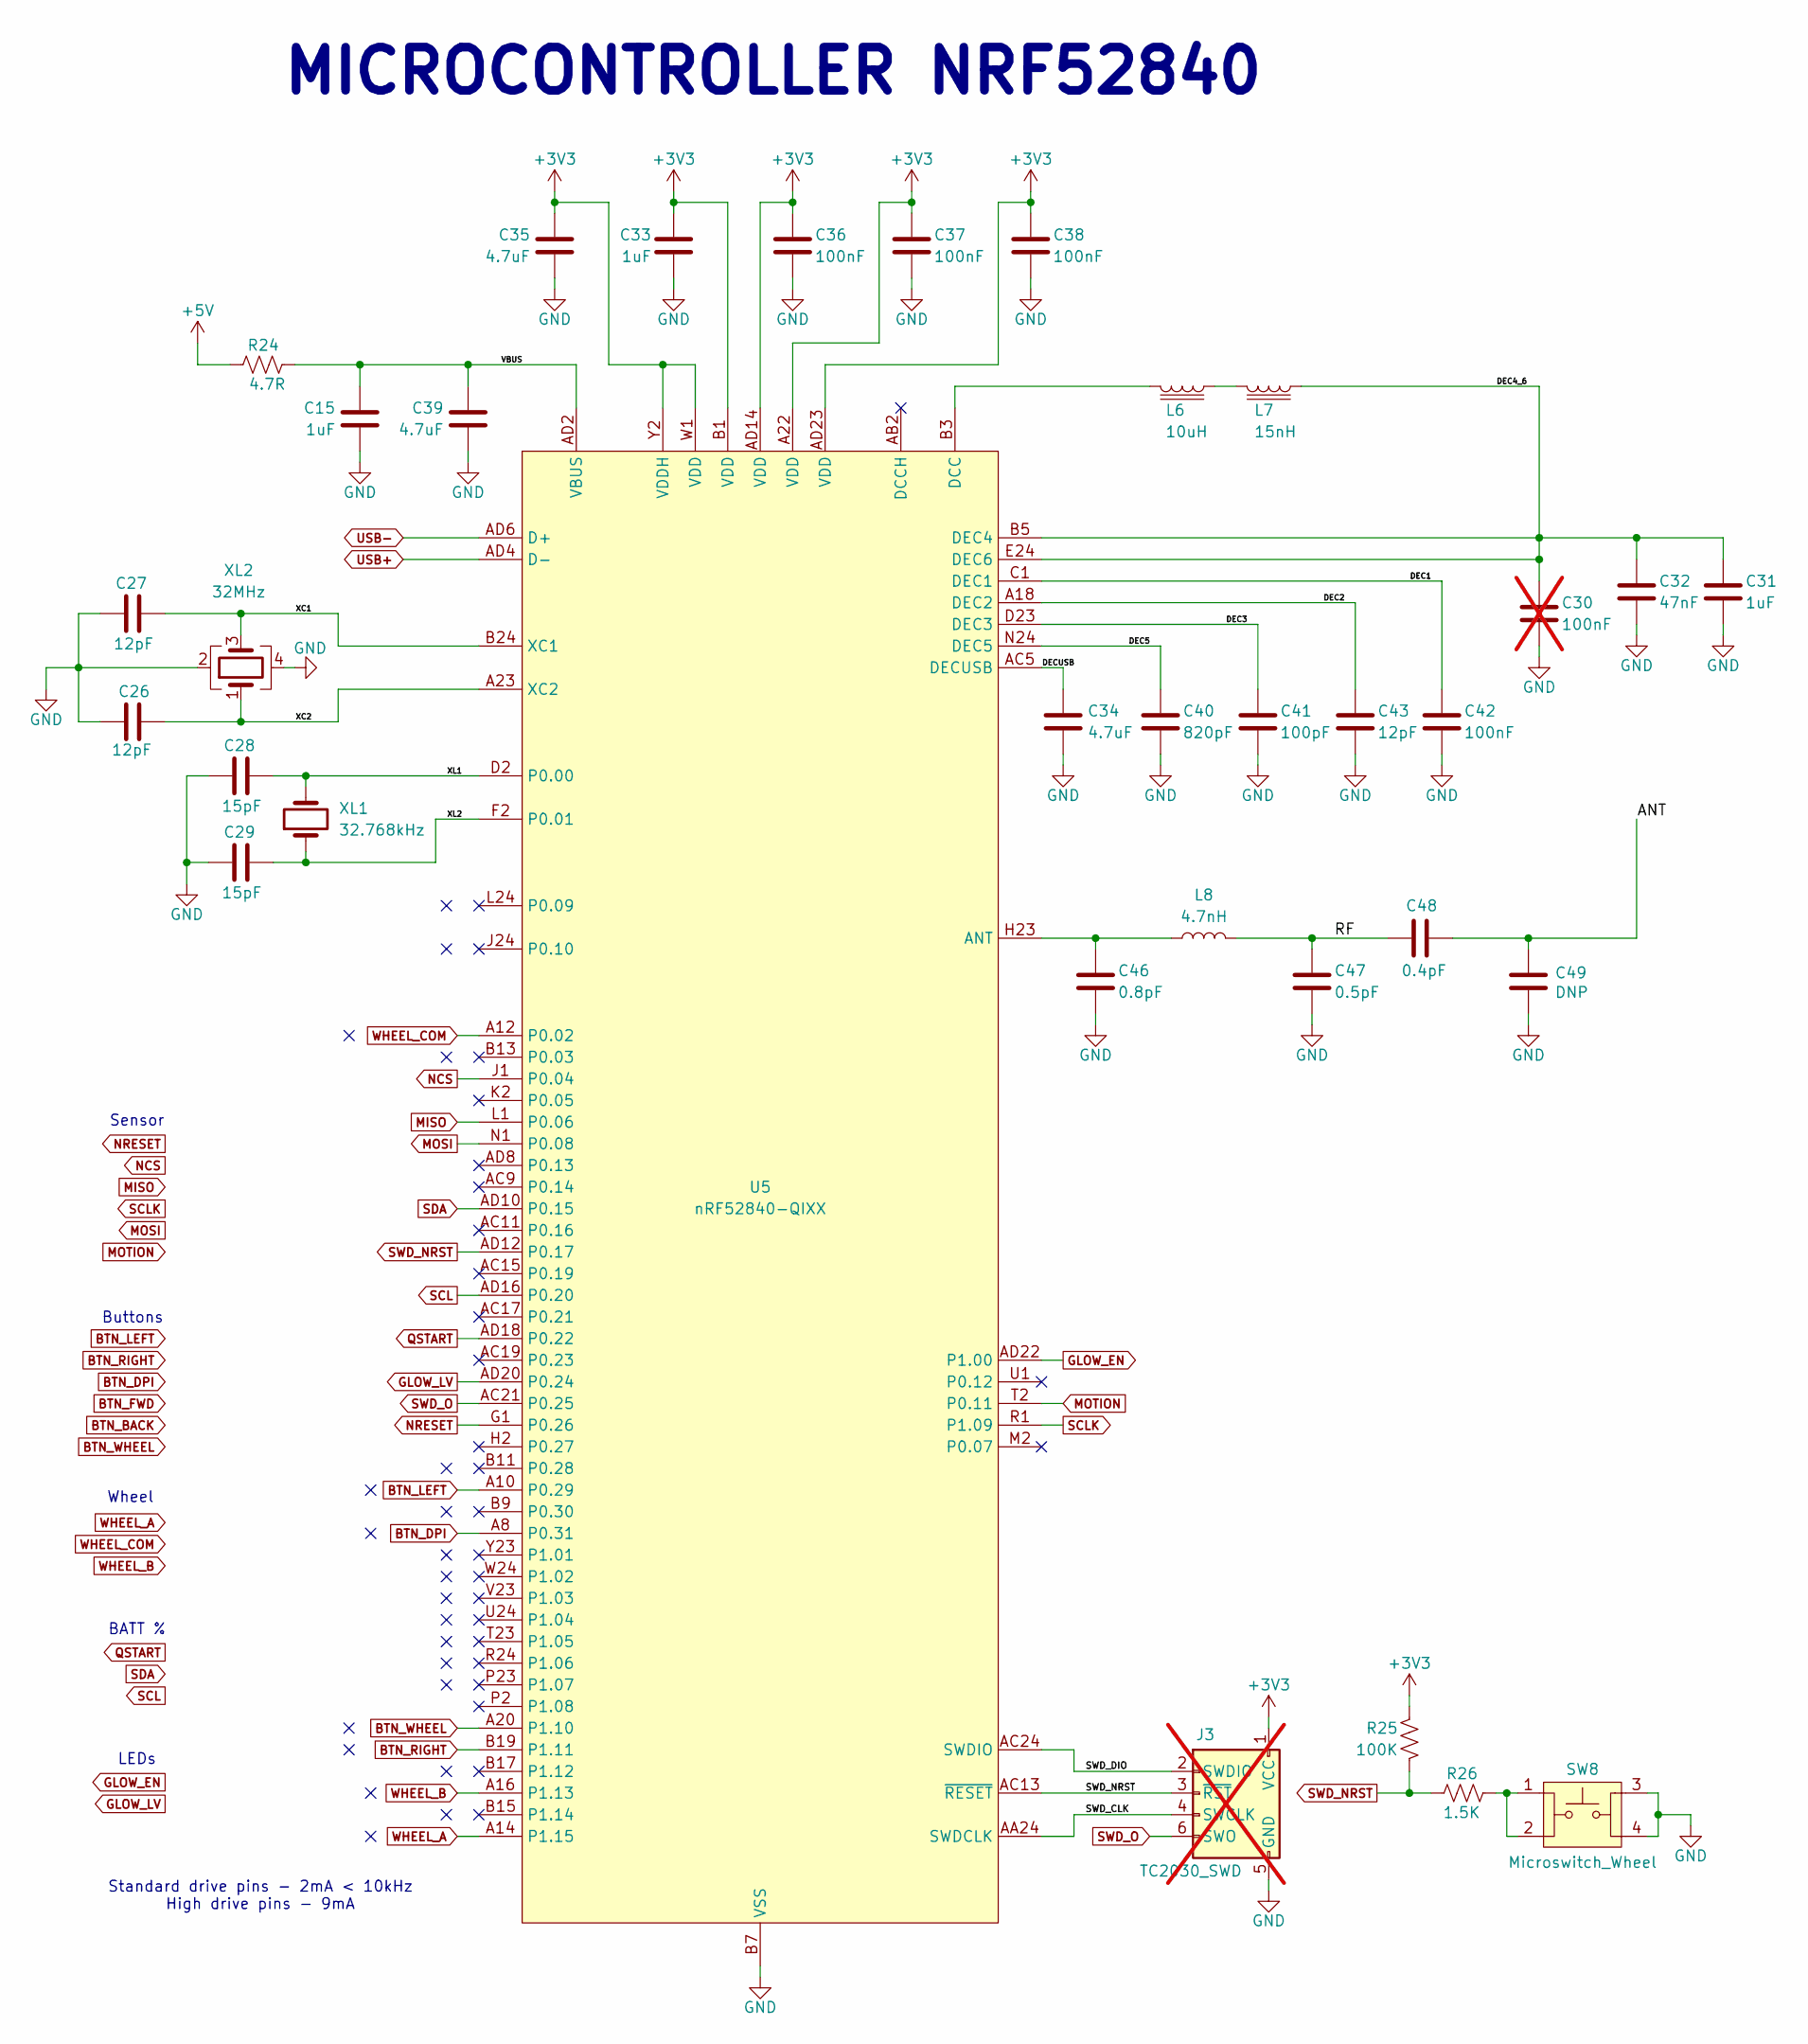
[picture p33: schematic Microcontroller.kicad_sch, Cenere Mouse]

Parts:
C15, C31, C33: 1uF; C_0402_1005Metric; Part Number CL05A105KA5NQNC; JLCPCB PN C52923
C26, C27, C43: 12pF; C_0402_1005Metric; Part Number 0402CG120J500NT; JLCPCB PN C1547
C28, C29: 15pF; C_0402_1005Metric; Part Number 0402CG150J500NT; JLCPCB PN C1548
C30: 100nF; C_0201_0603Metric; not fitted
C32: 47nF; C_0402_1005Metric; Part Number CC0402KRX7R9BB473; JLCPCB PN C272875
C34, C35, C39: 4.7uF; C_0402_1005Metric; Part Number CL05A475MP5NRNC; JLCPCB PN C23733
C36, C37, C38, C42: 100nF; C_0402_1005Metric; Part Number CL05B104KB54PNC; JLCPCB PN C307331
C40: 820pF; C_0402_1005Metric; Part Number CL05C821JB5NNNC; JLCPCB PN C307452
C41: 100pF; C_0402_1005Metric; Part Number 0402CG101J500NT; JLCPCB PN C1546
C46: 0.8pF; C_0402_1005Metric; Part Number GJM1555C1HR80WB01D; JLCPCB PN C88902
C47: 0.5pF; C_0402_1005Metric; Part Number GCM1555C1HR50WA16D; JLCPCB PN C2912277
C48: 0.4pF; Z0201 RF Antenna Path; Part Number GRM0335C1ER40WA01D; JLCPCB PN C710805
C49: DNP; Z0201 RF Antenna Path
J3: TC2030_SWD; CON_TC2030_outlined; not fitted
L6: 10uH; L_0603_1608Metric; Part Number LBMF1608T100M; JLCPCB PN C86752
L7: 15nH; L_0402_1005Metric; Part Number LQW15AN15NG80D; JLCPCB PN C668460
L8: 4.7nH; L_0402_1005Metric; Part Number LQG15HS4N7S02D; JLCPCB PN C86065
R24: 4.7R; R_0603_1608Metric; Part Number 0603WAF470KT5E; JLCPCB PN C23164
R25: 100K; R_0402_1005Metric; Part Number 0402WGF1003TCE; JLCPCB PN C25741
R26: 1.5K; R_0402_1005Metric; Part Number 0402WGF1501TCE; JLCPCB PN C25867
SW8: Microswitch_Wheel; KEY-SMD_4P-L4.2-W3.2-P2.20-LS4.6; Part Number SKRPACE010; JLCPCB PN C139797
U5: nRF52840-QIXX; Nordic_AQFN-73-1EP_7x7mm_P0.5mm; Part Number NRF52840-QIAA-R; JLCPCB PN C190794
XL1: 32.768kHz; Crystal_SMD_2012-2Pin_2.0x1.2mm; Part Number XKHEL89CGI-112YLC-32.768K; JLCPCB PN C7500573
XL2: 32MHz; Crystal_SMD_2016-4Pin_2.0x1.6mm; Part Number XL7EL89CKI-111YLC-32M; JLCPCB PN C2965582

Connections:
+3V3: C33.1, C35.1, C36.1, C37.1, C38.1, J3.1 (VCC), R25.1, U5.A22 (VDD), U5.AD14 (VDD), U5.AD23 (VDD), U5.B1 (VDD), U5.W1 (VDD), U5.Y2 (VDDH); also elsewhere on the board
+5V: R24.1; also elsewhere on the board
/Microcontroller/ANT: C48.2, C49.2
/Microcontroller/DEC1: C42.1, U5.C1 (DEC1)
/Microcontroller/DEC2: C43.2, U5.A18 (DEC2)
/Microcontroller/DEC3: C41.1, U5.D23 (DEC3)
/Microcontroller/DEC4_6: C30.1, C31.1, C32.1, L7.1, U5.B5 (DEC4), U5.E24 (DEC6)
/Microcontroller/DEC5: C40.1, U5.N24 (DEC5)
/Microcontroller/DECUSB: C34.1, U5.AC5 (DECUSB)
/Microcontroller/RF: C47.1, C48.1, L8.2
/Microcontroller/SWD_CLK: J3.4 (SWCLK), U5.AA24 (SWDCLK)
/Microcontroller/SWD_DIO: J3.2 (SWDIO), U5.AC24 (SWDIO)
/Microcontroller/VBUS: C15.1, C39.1, R24.2, U5.AD2 (VBUS)
/Microcontroller/XC1: C27.2, U5.B24 (XC1), XL2.3
/Microcontroller/XC2: C26.1, U5.A23 (XC2), XL2.1
/Microcontroller/XL1: C28.2, U5.D2 (P0.00), XL1.2
/Microcontroller/XL2: C29.2, U5.F2 (P0.01), XL1.1
BTN_DPI: U5.A8 (P0.31); also elsewhere on the board
BTN_LEFT: U5.A10 (P0.29); also elsewhere on the board
BTN_RIGHT: U5.B19 (P1.11); also elsewhere on the board
BTN_WHEEL: U5.A20 (P1.10); also elsewhere on the board
GLOW_EN: U5.AD22 (P1.00); also elsewhere on the board
GLOW_LV: U5.AD20 (P0.24); also elsewhere on the board
GND: C15.2, C26.2, C27.1, C28.1, C29.1, C30.2, C31.2, C32.2, C33.2, C34.2, C35.2, C36.2, C37.2, C38.2, C39.2, C40.2, C41.2, C42.2, C43.1, C46.2, C47.2, C49.1, J3.5 (GND), SW8.3, SW8.4, U5.B7 (VSS), U5.EP (VSS), U5.F23 (VSS_PA), XL2.2, XL2.4; also elsewhere on the board
MISO: U5.L1 (P0.06); also elsewhere on the board
MOSI: U5.N1 (P0.08); also elsewhere on the board
MOTION: U5.T2 (P0.11); also elsewhere on the board
NCS: U5.J1 (P0.04); also elsewhere on the board
NRESET: U5.G1 (P0.26); also elsewhere on the board
unnamed: L6.1, L7.2
unnamed: R26.2, SW8.1, SW8.2
unnamed: C46.1, L8.1, U5.H23 (ANT)
unnamed: L6.2, U5.B3 (DCC)
QSTART: U5.AD18 (P0.22); also elsewhere on the board
SCL: U5.AD16 (P0.20); also elsewhere on the board
SCLK: U5.R1 (P1.09); also elsewhere on the board
SDA: U5.AD10 (P0.15); also elsewhere on the board
SWD_NRST: J3.3 (~RST), R25.2, R26.1, U5.AC13 (~RESET), U5.AD12 (P0.17)
SWD_O: J3.6 (SWO), U5.AC21 (P0.25)
USB+: U5.AD4 (D-); also elsewhere on the board
USB-: U5.AD6 (D+); also elsewhere on the board
WHEEL_A: U5.A14 (P1.15); also elsewhere on the board
WHEEL_B: U5.A16 (P1.13); also elsewhere on the board
WHEEL_COM: U5.A12 (P0.02); also elsewhere on the board

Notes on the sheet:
Standard drive pins - 2mA < 10kHz High drive pins - 9mA
BATT %
Buttons
MICROCONTROLLER NRF52840
Sensor
Wheel
LEDs

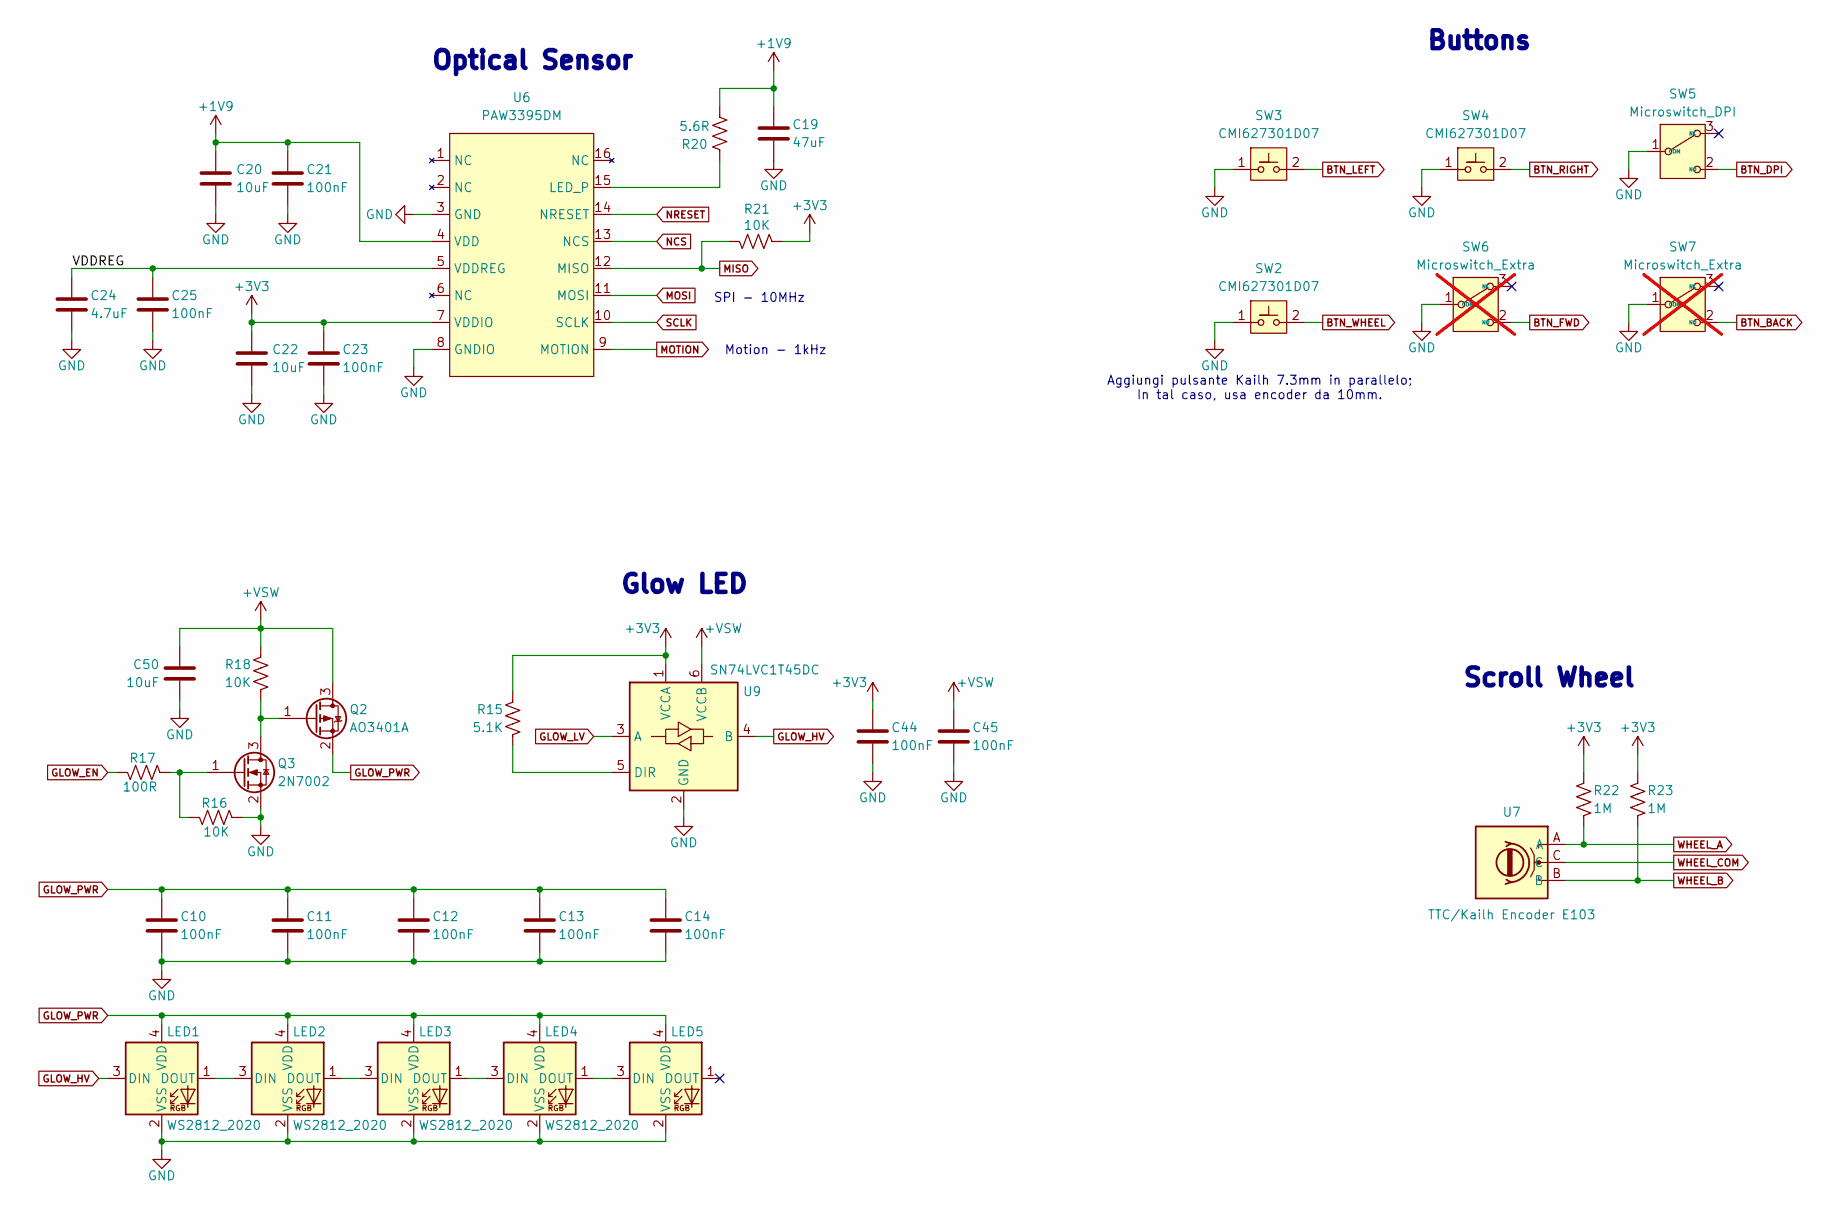
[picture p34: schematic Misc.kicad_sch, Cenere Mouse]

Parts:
C10, C11, C12, C13, C14, C21, C23, C25, C44, C45: 100nF; C_0402_1005Metric; Part Number CL05B104KB54PNC; JLCPCB PN C307331
C19: 47uF; C_1210_3225Metric; Part Number GRM32ER71A476KE15L; JLCPCB PN C84494
C20, C22, C50: 10uF; C_0805_2012Metric; Part Number CL21B106KOQNNNE; JLCPCB PN C95841
C24: 4.7uF; C_0805_2012Metric; Part Number CGA0805X7R475K350MT; JLCPCB PN C6119943
LED1, LED2, LED3, LED4, LED5: WS2812_2020; LED_WS2812_2020; Part Number WS2812B-2020; JLCPCB PN C965555
Q2: AO3401A; SOT-23; Part Number AO3401A; JLCPCB PN C347476
Q3: 2N7002; SOT-23; Part Number 2N7002; JLCPCB PN C8545
R15: 5.1K; R_0603_1608Metric; Part Number 0603WAF5101T5E; JLCPCB PN C23186
R16, R18, R21: 10K; R_0603_1608Metric; Part Number 0603WAF1002T5E; JLCPCB PN C25804
R17: 100R; R_0603_1608Metric; Part Number 0603WAF1000T5E; JLCPCB PN C22775
R20: 5.6R; R_0805_2012Metric; Part Number 0805W8F560KT5E; JLCPCB PN C17729
R22, R23: 1M; R_0603_1608Metric; Part Number 0603WAF1004T5E; JLCPCB PN C22935
SW2, SW3, SW4: CMI627301D07; SW_Tactile_SPST_ Kailh_6x6x7.3mm_Mute_Silent; Part Number CMI627301D07; JLCPCB PN C400268
SW5: Microswitch_DPI; SW_Tactile_SPDT_Omron_D2F; Part Number CMI126603D09; JLCPCB PN C400257
SW6, SW7: Microswitch_Extra; SW_Tactile_SPDT_Omron_D2F; not fitted
U6: PAW3395DM; PixArt_PDIP-16_10.9x16.2mm_P1.78mm; Part Number PAW3395
U7: TTC/Kailh Encoder E103; TTC E103 - Kailh Rotary Encoder
U9: SN74LVC1T45DC; SOT-363_SC-70-6; Part Number SN74LVC1T45DC; JLCPCB PN C9382

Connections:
+1V9: C19.1, C20.1, C21.1, R20.2, U6.4 (VDD); also elsewhere on the board
+3V3: C22.1, C23.1, C44.1, R15.1, R21.1, R22.1, R23.1, U6.7 (VDDIO), U9.1 (VCCA); also elsewhere on the board
+VSW: C45.1, C50.1, Q2.3 (D), R18.1, U9.6 (VCCB); also elsewhere on the board
/Misc/VDDREG: C24.1, C25.1, U6.5 (VDDREG)
BTN_DPI: SW5.2 (NO); also elsewhere on the board
BTN_LEFT: SW3.2; also elsewhere on the board
BTN_RIGHT: SW4.2; also elsewhere on the board
BTN_WHEEL: SW2.2; also elsewhere on the board
GLOW_EN: R17.1; also elsewhere on the board
GLOW_HV: LED1.3 (DIN), U9.4 (B)
GLOW_LV: U9.3 (A); also elsewhere on the board
GLOW_PWR: C10.1, C11.1, C12.1, C13.1, C14.1, LED1.4 (VDD), LED2.4 (VDD), LED3.4 (VDD), LED4.4 (VDD), LED5.4 (VDD), Q2.2 (S)
GND: C10.2, C11.2, C12.2, C13.2, C14.2, C19.2, C20.2, C21.2, C22.2, C23.2, C24.2, C25.2, C44.2, C45.2, C50.2, LED1.2 (VSS), LED2.2 (VSS), LED3.2 (VSS), LED4.2 (VSS), LED5.2 (VSS), Q3.2 (S), R16.2, SW2.1, SW3.1, SW4.1, SW5.1 (COM), SW6.1 (COM), SW7.1 (COM), U6.3 (GND), U6.8 (GNDIO), U9.2 (GND); also elsewhere on the board
MISO: R21.2, U6.12 (MISO); also elsewhere on the board
MOSI: U6.11 (MOSI); also elsewhere on the board
MOTION: U6.9 (MOTION); also elsewhere on the board
NCS: U6.13 (NCS); also elsewhere on the board
NRESET: U6.14 (NRESET); also elsewhere on the board
unnamed: LED1.1 (DOUT), LED2.3 (DIN)
unnamed: LED2.1 (DOUT), LED3.3 (DIN)
unnamed: LED3.1 (DOUT), LED4.3 (DIN)
unnamed: LED4.1 (DOUT), LED5.3 (DIN)
unnamed: Q2.1 (G), Q3.3 (D), R18.2
unnamed: Q3.1 (G), R16.1, R17.2
unnamed: R20.1, U6.15 (LED_P)
unnamed: R15.2, U9.5 (DIR)
SCLK: U6.10 (SCLK); also elsewhere on the board
WHEEL_A: R22.2, U7.A; also elsewhere on the board
WHEEL_B: R23.2, U7.B; also elsewhere on the board
WHEEL_COM: U7.C; also elsewhere on the board

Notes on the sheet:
SPI - 10MHz
Glow LED
Motion - 1kHz
Scroll Wheel
Optical Sensor
Buttons
Aggiungi pulsante Kailh 7.3mm in parallelo; In tal caso, usa encoder da 10mm.

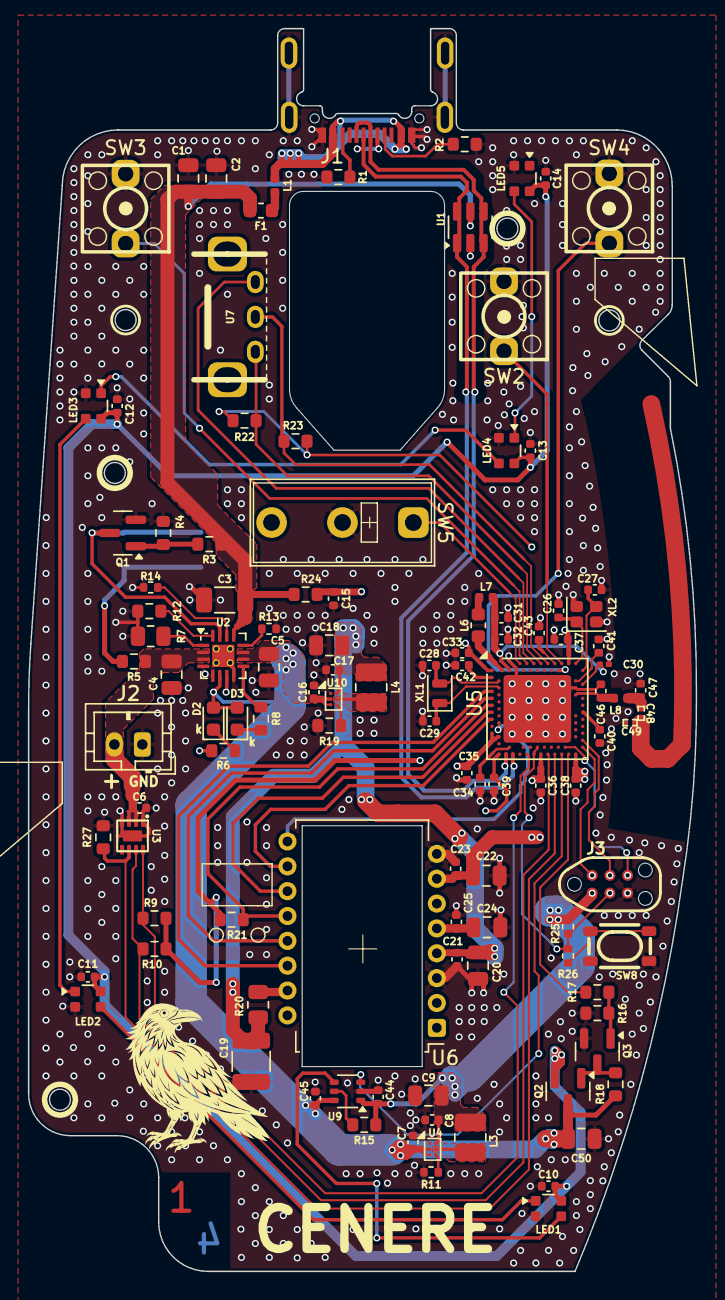
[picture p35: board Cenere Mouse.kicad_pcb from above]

Board: 4 copper layers, 47.8 x 89.0 mm, 114 parts (1 on the bottom side), 77 nets.

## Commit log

2025-08-20 Initial commit
    Initial commit including:
    - Kicad design files
    - Electronics docs misc.
    - Licensing
    - Readme draft
    [ASVTX-13.STEP, Alps Encoder 10mm EC10E1220501.stp, Cenere Mouse.kicad_pcb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]
2025-08-22 Minor improvements (detailed list attached)
    - Updated JST Connector to a more common PH 2.0mm one;
    - Added some helpful silkscreen;
    - Retouched some tracks;
    -
    Updated schematic symbols information to help “automatically” generate JLC BOM;
    -
    Adjusted Vias Annular ring sizes and clearances cleanup for JLC manufacturing;
    - Adjusted gitgnore to include .csv and .xml to show BOM files on Github;
    [Cenere Mouse.kicad_pcb, Cenere Mouse.kicad_sch, Microcontroller.kicad_sch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]
